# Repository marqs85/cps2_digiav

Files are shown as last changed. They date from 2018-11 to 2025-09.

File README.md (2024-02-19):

CPS2 digital AV interface (Rev 2)
==============

Overview
--------------------------
cps2_digiav is an add-on for Capcom CP System II and some other arcade boards. It enables digital video and audio output via HDMI connector. The project consists of a common interface PCB (`pcb/`) and board-specific FPGA firmware (`board/<board>/output_files/cps2_digiav.jic`).

Supported boards
--------------------------
* CPS1 (89626A)
* CPS2
* CPS3
* Neo Geo (MV1C, AES3-3 and AES3-6, possibly others as well)
* Toaplan V2

Hardware
--------------------------
The add-on [PCB](https://oshpark.com/shared_projects/fxG9hou9) design can be self-built or bought [pre-assembled](https://videogameperfection.com/products/cps2-cps3-digital-av-interface-diy-kit/).

* Installation typically requires a small number of additional components which are listed in board-specific READMEs.

More info and discussion
--------------------------
* [Forum topic](http://shmups.system11.org/viewtopic.php?f=6&t=59479&p=1266977)

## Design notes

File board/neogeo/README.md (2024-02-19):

CPS2 digital AV interface (Neo Geo version)
==============

Features (current)
--------------------------
* framelocked 59.19Hz output (59.60Hz on AES) with max. 40 scanline latency
  * 240p_CRT (for 15kHz CRTs and capture)
  * 480p_CRT (for 31kHz CRTs)
  * 720p (CEA)
  * 1280x1024 (VESA)
  * 1080p (CEA, vertical 4x)
  * 1080p (CEA, vertical 5x) [default]
  * 1600x1200 (VESA)
  * 1920x1200 (CVT-RB)
  * 1920x1440 (CVT-RB)
* 24bit/48kHz audio output

Installation
--------------------------
The add-on board can be installed on top of MVS PCB or AES home console. Installation instructions are provided for MV1C, NEO-AES3-3 and NEO-AES3-6 models, but the mod should be compatible with others too. The following additional parts are required:

* 2pcs 0805 10u SMD ceramic capacitors (MV1C only)
* ribbon cable
* [audio ADC board](../../pcb_neogeo_aadc) for models without NEO-YSA2 chip (present in MV1C and some others)
* hookup for PCB buttons
  * if using JAMMA buttons: 2x 10cm wires
  * if using separate buttons: 2pcs 0603 10k SMD resistors and TL2243 switch (or 2 external buttons connecting "vol+" and "vol-" pads to GND when pressed)

Installation instructions are found in doc/install.md (MV1C) and doc/install_aes.md (AES).

Usage
--------------------------
Board is controlled via TL2243 (or via 2 external buttons depending on installation).

Bindings outside OSD:
* VOL- (hold 1.5s): enable OSD

Bindings inside OSD:
* VOL-: next option
* VOL+: next value / select function

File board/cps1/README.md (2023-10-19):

CPS2 digital AV interface (CPS1 version)
==============

Features (current)
--------------------------
* framelocked 59.64Hz output with max. 40 scanline latency
  * 240p_CRT (for 15kHz CRTs and capture)
  * 480p_CRT (for 31kHz CRTs)
  * 720p (CEA)
  * 1280x1024 (VESA)
  * 1080p (CEA, vertical 4x)
  * 1080p (CEA, vertical 5x) [default]
  * 1600x1200 (VESA)
  * 1920x1200 (CVT-RB)
  * 1920x1440 (CVT-RB)
* 24bit/48kHz audio output

Installation
--------------------------
The add-on board can be installed on top of CPS1 A-board (89626A revisions currently supported). The following additional parts are required:

* cps1_adapter PCB and related parts, see pcb_cps1_adapter folder
* 3pcs 2x5 U-type pin headers
* ribbon cable
* coaxial cable (~40cm)
* hookup for PCB buttons
  * if using JAMMA buttons: 2x 15cm wires
  * if using external buttons: wires and 2pcs 0603 10k SMD resistors
  * if using CPS2 I/O Interface, 1pcs of XHP-2, 1pcs ASXHSXH22K305 and 2pcs 0603 10k SMD resistors

Installation instructions are found in doc/install.md .

Usage
--------------------------
Board is controlled via two external buttons.

Bindings outside OSD:
* VOL- (hold 1.5s): enable OSD
* VOL+ (hold 1.5s): toggle scanline mode

Bindings inside OSD:
* VOL-: next option
* VOL+: next value / select function

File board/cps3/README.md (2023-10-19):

CPS2 digital AV interface (CPS3 version)
==============

Features (current)
--------------------------
* framelocked 59.60Hz output with max. 40 scanline latency
  * 240p_CRT (for 15kHz CRTs and capture)
  * 480p_CRT (for 31kHz CRTs)
  * 720p (CEA)
  * 1280x1024 (VESA) [std. aspect only]
  * 1080p (CEA, vertical 4x)
  * 1080p (CEA, vertical 5x) [default]
  * 1600x1200 (VESA) [std. aspect only]
  * 1920x1200 (CVT-RB)
  * 1920x1440 (CVT-RB) [std. aspect only]
* 24bit/48kHz audio output
* supports CPS3 standard and widescreen modes

Installation
--------------------------
The add-on board can be installed on top of CPS3 board, preferably close to JAMMA connector. The following additional parts are required:
* ribbon cable (~15cm, at least 5x4=20 conductors)
* coaxial cable (~50cm total)
* kynar wire (~50cm total)
* hookup for PCB buttons
  * if using JAMMA buttons: 2x 25cm wires
  * if using separate buttons: 2pcs 0603 10k SMD resistors and TL2243 switch (or 2 external buttons connecting "vol+" and "vol-" pads to GND when pressed)
  * if using CPS2 I/O Interface, 1pcs of XHP-2, 2pcs ASXHSXH22K305 and 2pcs 0603 10k SMD resistors

Signal hookup points are listed in doc/cps3_hookup_points.txt and instructions are in doc/install.md .

Usage
--------------------------
Board is controlled via TL2243 (or via 2 external buttons depending on installation).

Bindings outside OSD:
* VOL- (hold 1.5s): enable OSD
* VOL+ (hold 1.5s): toggle scanline mode

Bindings inside OSD:
* VOL-: next option
* VOL+: next value / select function

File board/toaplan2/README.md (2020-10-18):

CPS2 digital AV interface (Toaplan V2 version)
==============

Features (current)
--------------------------
* framelocked 59.4Hz output with max. 40 scanline latency
  * 240p_CRT (for 15kHz CRTs and capture)
  * 480p_CRT (for 31kHz CRTs)
  * 720p (CEA)
  * 1280x1024 (VESA)
  * 1080p (CEA, vertical 4x)
  * 1080p (CEA, vertical 5x) [default]
  * 1600x1200 (VESA)
  * 1920x1200 (CVT-RB)
  * 1920x1440 (CVT-RB)
* 24bit/48kHz audio output

Installation
--------------------------
The add-on board can be installed on top of Toaplan V2 boards. The following additional parts are required:

* cps1_adapter PCB and related parts, see pcb_cps1_adapter folder
* 2pcs 0603 10k SMD resistors and TL2243 switch (or 2 external buttons connecting "vol+" and "vol-" pads to GND when pressed)
* ribbon cable
* coaxial cable (~40cm)

Installation instructions are found in doc/install.md .

Usage
--------------------------
Board is controlled via TL2243 (or via 2 external buttons depending on installation).

Bindings outside OSD:
* VOL- (hold 1.5s): enable OSD
* VOL+ (hold 1.5s): toggle scanline mode

Bindings inside OSD:
* VOL-: next option
* VOL+: next value / select function

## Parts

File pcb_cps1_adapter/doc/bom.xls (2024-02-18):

Id | Designator | Package | Quantity | Designation | Supplier and ref
1 | U1 | TSSOP-16_4.4x5mm_P0.65mm | 1 | 74LVC112 | https://www.digikey.fi/product-detail/en/texas-instruments/SN74LVC112APWR/296-8450-1-ND/377408
2 | U2 | SSOP-20_5.3x7.2mm_P0.65mm | 1 | WM8782 | https://www.digikey.fi/product-detail/en/cirrus-logic-inc/WM8782SEDS-V/598-2466-ND/5036698
3 | U3, | Package_SO:SOIC-16_3.9x9.9mm_P1.27mm | 1 | 74LVC157 | https://www.digikey.fi/en/products/detail/texas-instruments/SN74LVC157ADR/562891
4 | J1,J2,J3 | BCS-105-L-D-PE-BE | 3 | Conn_02x05_Counter_Clockwise | https://www.digikey.fi/products/en?keywords=BCS-105-L-D-PE-BE%20
5 | C2,C4,C6,C7,C9,C11 | SM0603_Capa_libcms | 6 | 0.1u | https://www.digikey.fi/product-detail/en/samsung-electro-mechanics/CL10B104KB8NNNC/1276-1000-1-ND/3889086
6 | C1,C3,C5,C8,C10 | SM0603_Capa_libcms | 5 | 10u | https://www.digikey.fi/product-detail/en/avx-corporation/0603ZD106KAT2A/478-10766-1-ND/7536554
7 | R1, R5 | SM0603_Resistor_libcms | 2 | 1.8k | https://www.digikey.fi/product-detail/en/yageo/RC0603FR-071K8L/311-1.80KHRCT-ND/729821
8 | R2, R3, R6 | SM0603_Resistor_libcms | 3 | 3.3k | https://www.digikey.fi/product-detail/en/yageo/RT0603FRE073K3L/YAG3354CT-ND/5418059
9 | R4 | SM0603_Resistor_libcms | 1 | 1M | https://www.digikey.fi/product-detail/en/yageo/RC0603FR-071ML/311-1.00MHRCT-ND/729791
10 | J4,J5 |  | 1 |  | https://www.digikey.fi/product-detail/en/samtec-inc/TSW-120-07-G-S/SAM1029-20-ND/1101307

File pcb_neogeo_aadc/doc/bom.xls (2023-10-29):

Ref | Qnty | Value | Cmp name | Package | MPN | Supplier and ref
C1, C2, C5, C7, C8, C9, | 6 | 10u | C_Small | custom_components:SM0603_Capa_libcms | CL10A106KP8NNNC
C3, C4, C6, C10, | 4 | 0.1u | C_Small | custom_components:SM0603_Capa_libcms | CC0603KRX7R9BB104
C11, C12, | 2 | 1u | C_Small | custom_components:SM0603_Capa_libcms | CL10A105KB8NNNC
R1, | 1 | 10k | R_Small | custom_components:SM0603_Resistor_libcms | 0603WAF1002T5E
R2, R3, | 2 | 15k | R_Small | custom_components:SM0603_Resistor_libcms | 0603WAF1502T5E
R4, R5, | 2 | 5k | R_Small | custom_components:SM0603_Resistor_libcms | 0603WAF4701T5E
R6, | 1 | 3.3k | R_Small | custom_components:SM0603_Resistor_libcms | 0603WAF3301T5E
U1, | 1 | 74LVC1G17 | 74LVC1G17 | Package_TO_SOT_SMD:SOT-23-5_HandSoldering | SN74LVC1G17DBVR
U2, | 1 | WM8782 | WM8782 | custom_components:TSSOP-20_4.4x6.5mm_Pitch0.65mm_Handsoldering | WM8782SEDS/RV
U3, | 1 | TLV70033_SOT23-5 | TLV70033_SOT23-5 | Package_TO_SOT_SMD:SOT-23-5_HandSoldering | TLV70033DDCR

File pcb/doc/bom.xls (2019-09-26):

Id | Designator | Package | Quantity | Designation | Supplier and ref | Notes
1 | P1 | VASCH5x2 | 1 | JTAG_CONN | https://www.digikey.fi/products/en?keywords=30310-6002HB | Developers should consider right angle unshrouded pin header which fits in the case with cable connected
2 | U15 | SOT-23-5_Handsoldering | 1 | TLV70018 | https://www.digikey.fi/product-detail/en/texas-instruments/TLV70018DDCT/296-25270-1-ND/2176448
3 | U12,U14 | SOT-23-5_Handsoldering | 2 | TLV70012 | https://www.digikey.fi/product-detail/en/texas-instruments/TLV70012DDCT/296-27218-1-ND/2260735
4 | U13 | SOT-23-5_Handsoldering | 1 | TLV70025 | https://www.digikey.fi/product-detail/en/texas-instruments/TLV70025DDCT/296-25568-1-ND/2197047
5 | J4 | HDMI_CONN-10029449-111RLF | 1 | HDMI_CONN | https://www.digikey.fi/product-detail/en/amphenol-fci/10029449-111RLF/609-4614-1-ND/2785376
6 | R46,R45,R1,R2,R5 | SM0603_Resistor_libcms | 5 | 2.2k | https://www.digikey.fi/product-detail/en/yageo/RC0603FR-072K2L/311-2.20KHRCT-ND/729963
7 | F2 | SM0603_Resistor_libcms | 1 | MF-FSMF020X-2 | https://www.digikey.fi/product-detail/en/bourns-inc/MF-FSMF020X-2/MF-FSMF020X-2CT-ND/2039387
8 | R41,R22,R21,R18,R17,R16,R6 | SM0603_Resistor_libcms | 7 | 10k | https://www.digikey.fi/product-detail/en/susumu/RR0816P-103-D/RR08P10.0KDCT-ND/432748
9 | FB4,FB2,FB1,FB3 | SM0603_Resistor_libcms | 4 | MPZ1608S221A | https://www.digikey.fi/product-detail/en/445-1565-1-ND/445-1565-1-ND/571895
10 | R24,R19,R4 | SM0603_Resistor_libcms | 3 | 4.7k | https://www.digikey.fi/product-detail/en/yageo/RC0603FR-074K7L/311-4.70KHRCT-ND/730159
11 | R23 | SM0603_Resistor_libcms | 1 | 25 | https://www.digikey.fi/product-detail/en/vishay-dale/CRCW060324R9FKEA/541-24.9HCT-ND/1179624
12 | R20 | SM0603_Resistor_libcms | 1 | 1k | https://www.digikey.fi/product-detail/en/yageo/RC0603FR-071KL/311-1.00KHRCT-ND/729790
13 | C108,C49,C1,C3,C10,C11,C12,C13,C26 | SM0603_Capa_libcms | 9 | 10u | https://www.digikey.fi/product-detail/en/murata-electronics-north-america/GRM188R60J106ME47D/490-3896-1-ND/965938
14 | C101,C99,C86,C85,C84,C83,C82,C81,C80,C79,C78,C77,C75,C74,C73,C69,C68,C67,C66,C65,C64,C63,C62,C61,C60,C59,C58,C57,C55,C54,C53,C51,C50,C48,C47,C46,C45,C44,C43,C42,C41,C40,C39,C6,C7,C8,C9,C14,C15,C16,C17,C18,C19,C20,C21,C22,C23,C25,C2 | SM0603_Capa_libcms | 59 | 0.1u | https://www.digikey.fi/product-detail/en/kemet/C0603C104K9RAC7867/399-15351-1-ND/7386749
15 | C98,C97,C96,C94,C92,C91,C89,C87 | SM0603_Capa_libcms | 8 | 1u | https://www.digikey.fi/product-detail/en/samsung-electro-mechanics/CL10A105MQ8NNNC/1276-1867-1-ND/3889953
16 | U10 | SOIC-8_3.9x4.9mm_Pitch1.27mm_Handsoldering | 1 | IS25LP016D-JBLE | https://www.digikey.fi/product-detail/en/issi-integrated-silicon-solution-inc/IS25LP016D-JBLE-TR/706-1599-1-ND/7672068
17 | C5 | SM0603_Capa_libcms | 1 | 47u | https://www.digikey.fi/product-detail/en/murata-electronics-north-america/GRM188R60J476ME15D/490-13247-1-ND/5877455
18 | D1 | SOD-323_Handsoldering | 1 | SD05-7 | https://www.digikey.fi/product-detail/en/diodes-incorporated/SD05-7/SD05DICT-ND/2052820
19 | R3 | SM0603_Resistor_libcms | 1 | 887 | https://www.digikey.fi/product-detail/en/panasonic-electronic-components/ERJ-PB3D8870V/P20277CT-ND/6214532
20 | U3,U4,U5 | TSSOP-20_4.4x6.5mm_Pitch0.65mm_Handsoldering | 3 | 74LVC245 | https://www.digikey.fi/product-detail/en/texas-instruments/SN74LVC245APWR/296-1233-1-ND/276501
21 | U16,U9,U8 | SOT-23-6_Handsoldering | 3 | SN74LVC2G17 | https://www.digikey.fi/product-detail/en/texas-instruments/SN74LVC2G17DBVR/296-13012-1-ND/479734
22 | D2,D3 | SLP2510P8 | 2 | RClamp0524P | https://www.digikey.fi/product-detail/en/semtech-corporation/RCLAMP0524PATCT/RCLAMP0524PACT-ND/2603616
23 | U1 | LQFP-64-1EP_10x10mm_Pitch0.5mm_Handsoldering | 1 | ADV7513 | https://www.digikey.fi/product-detail/en/analog-devices-inc/ADV7513BSWZ/ADV7513BSWZ-ND/3043405 | Alternative supplier: link (https://www.arrow.com/en/products/adv7513bswz/analog-devices)
24 | U2 | TQFP-144_thermal | 1 | 10CL025YE144C8N | https://www.digikey.fi/product-detail/en/intel-fpgas-altera/10CL025YE144C8G/10CL025YE144C8G-ND/7593572 | Alternative supplier: link (https://www.mouser.fi/ProductDetail/Intel-Altera/10CL025YE144C8G)
25 | U7 | SOT-223_Handsoldering | 1 | AP7361 | https://www.digikey.fi/product-detail/en/diodes-incorporated/AP7361C-33E-13/AP7361C-33E-13DICT-ND/5638331
26 | U6 | QFN-20-1EP_4x4mm_Pitch0.5mm_Handsoldering | 1 | SI5351C-B | https://www.digikey.fi/product-detail/en/silicon-labs/SI5351C-B-GM/336-2402-ND/3679850
27 | D4 | SOD-323_Handsoldering | 1 | ZHCS400TA | https://www.digikey.fi/product-detail/en/diodes-incorporated/ZHCS400TA/ZHCS400CT-ND/307928
28 | U11 | SSOP-28_5.3x10.2mm_Pitch0.65mm | 1 | SRC4190 | https://www.digikey.fi/product-detail/en/texas-instruments/SRC4190IDBR/296-41657-1-ND/5224401 | NOT ASSEMBLED
29 | J1,J2 | BCS-105-L-D-PE-BE | 2 | Conn_02x05 | https://www.digikey.fi/products/en?keywords=BCS-105-L-D-PE-BE%20 | Not needed for CPS3 installations
30 | R8,R7 | SM0603_Resistor_libcms | 2 | 10k | https://www.digikey.fi/product-detail/en/susumu/RR0816P-103-D/RR08P10.0KDCT-ND/432748 | Only for CPS1 and CPS3 installations
31 | SW1 | TL2243 | 1 | TL2243 | https://www.digikey.fi/product-detail/en/e-switch/TL2243/EG4606-ND/1794126 | Optional for CPS3 installation

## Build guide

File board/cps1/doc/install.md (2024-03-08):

A-board (revision 89626A-4) signal reference
--------------------------
[List of hookup points](./cps1_hookup_points.txt)

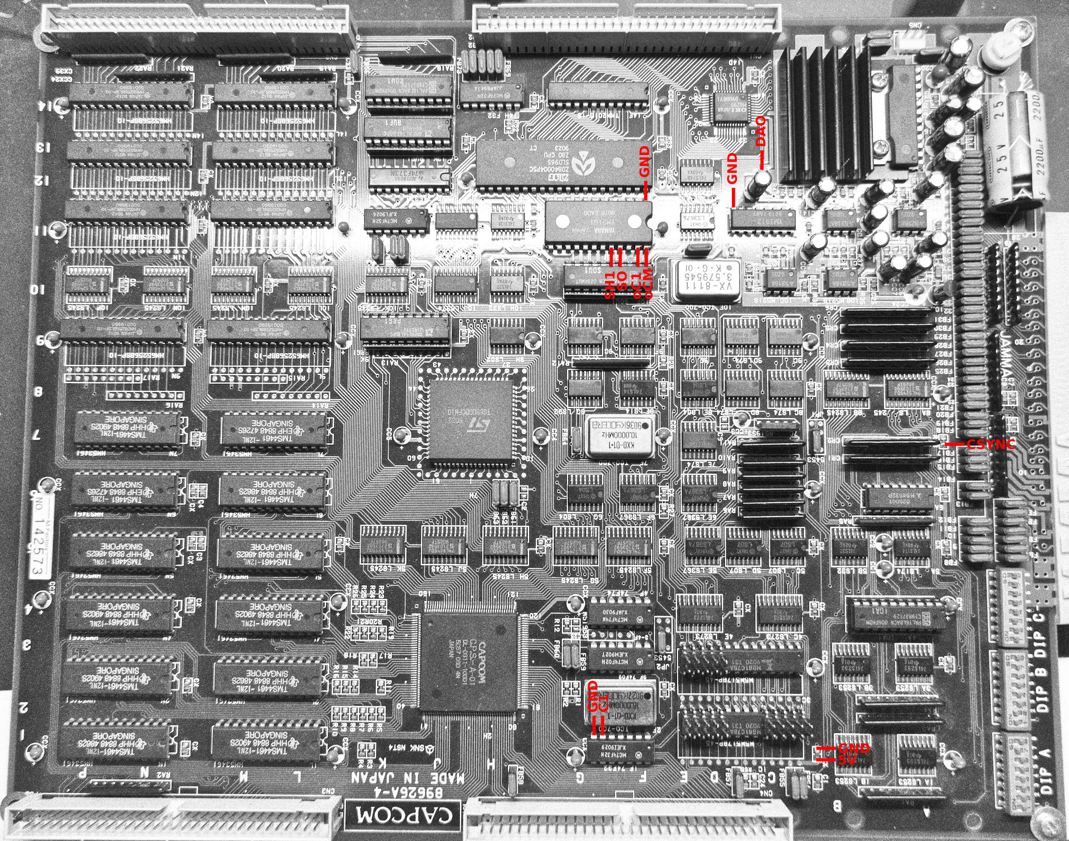
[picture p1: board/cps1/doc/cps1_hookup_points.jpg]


Step 1: Preparation
--------------------------

Solder 3pcs U-shaped 2x5 headers M5M RAM chips as shown in the image below. Solder BCS-105-L-D-PE-BE sockets on cps1_adapter (J1-3) and trim down pin metals underside the PCB. Make sure the adapter PCB fits in place before going forward. Solder R7+R8 (2x10k 0603 SMD resistors) on bottom of cps2_digiav board. Install cps2_digiav on top of adapter board via 4pcs 5-pin headers **without using spacers**.

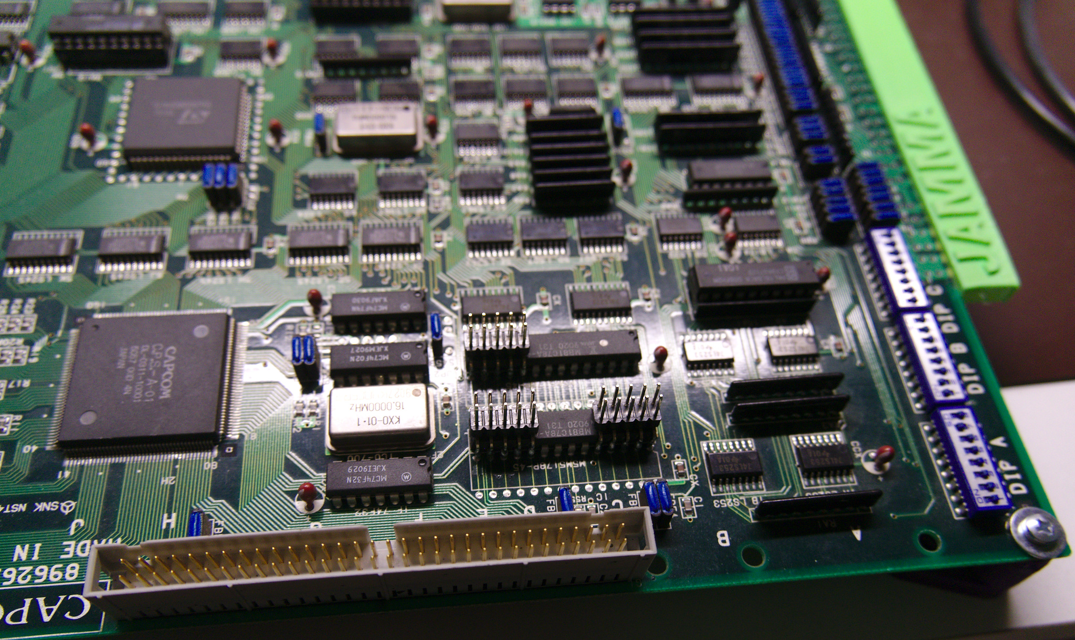
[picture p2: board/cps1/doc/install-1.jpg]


It is recommened to cover PAL 10A1 IC legs with electrical tape (at least on the side closer to PCB edge) as well as B-board bottom area above JTAG connector (full-length B-boards only). A-board resistor arrays (RA6-8) can be bent a little towards center so that adapter board PCB lies on level above them.

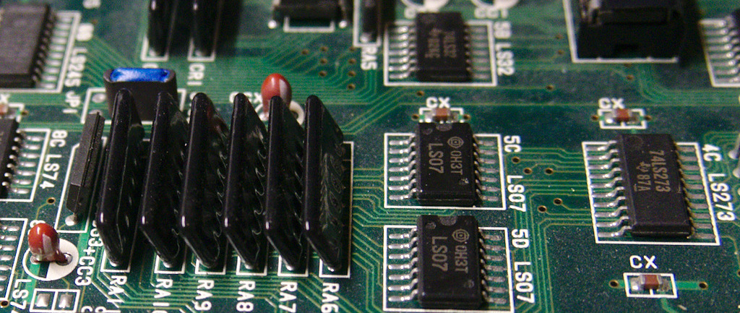
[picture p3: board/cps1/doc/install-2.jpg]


Step 2: Clock and sync signals
--------------------------

Clock is available on 74F32. It's mandatory to use a coax cable to avoid stability issues caused by noise. Composite sync is extracted from R28 as shown in the signal reference image (connect to HS pin on cps2_digiav).

Step 3: Audio, power and button signals
--------------------------

Audio is extracted from YM2151 and R49. Use coax cable for oCM and DAO signals.

The adapter board (since v1.3) has 4 QS_* pads reserved for CPS1 Multi installations (QSound support). On normal CPS1 installations these pads are left unconnected. With CPS1 Multi QS_SEL is connected to same endpoint as QSOUND wire and other QS_* pins to TDA1543 (it is recommended to use pin header like [this](https://www.digikey.fi/en/products/detail/sullins-connector-solutions/SWR25X-NRTC-S03-RB-BA/2769661)).

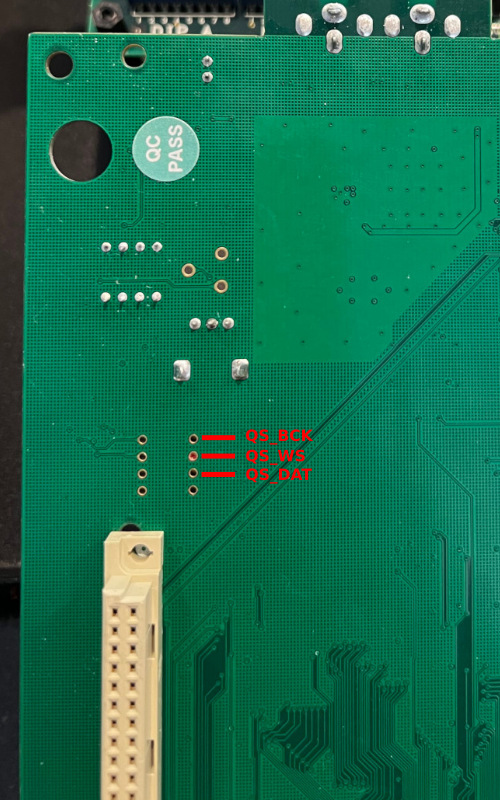
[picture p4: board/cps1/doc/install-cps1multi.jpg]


5V/GND can be extracted from certain CCX caps, e.g. the one shown in the signal reference image.

The board is operated via 2 keys which can be implemeted with one of the alternatives below:
* Wire vol-/vol+ pads to existing button lines on JAMMA connector (e.g. P1 credit & start).
* Wire two external pushbuttons to the board: one terminal to GND and another to vol-/vol+. Solder resistors R7 and R8 (10k 0603) to the board.
* If using CPS2 I/O Interface, vol-/vol+ pads can be wired to its up/down keys (see parts list on main README). R7 and R8 need to be installed as well.

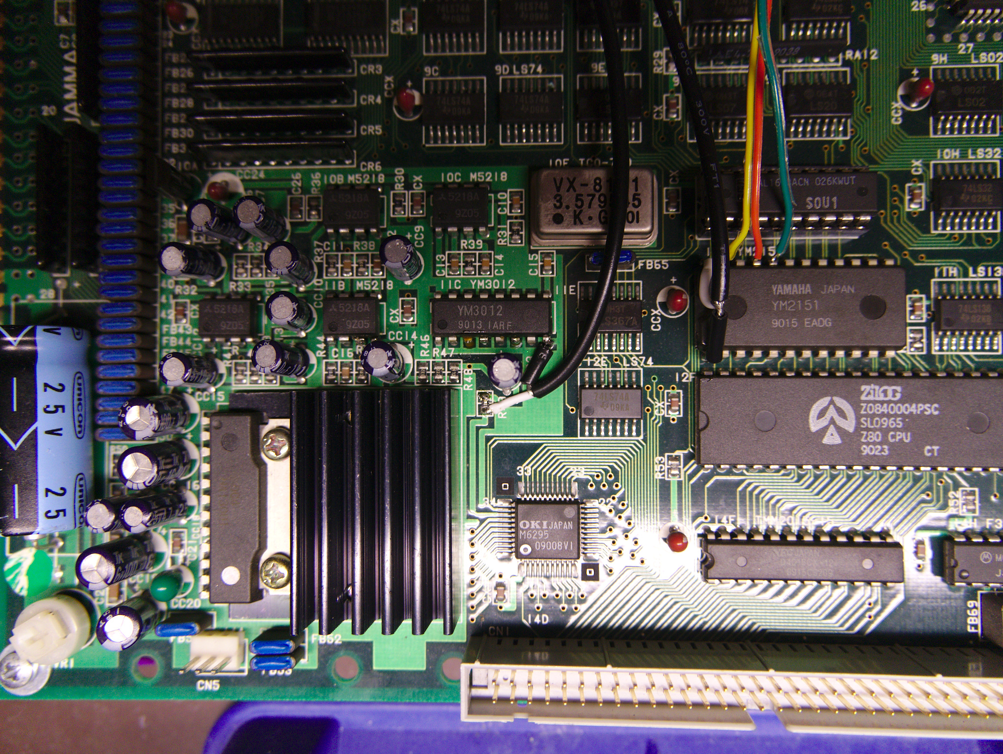
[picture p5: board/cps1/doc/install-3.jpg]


Step 4: Signals between cps1_adapter and cps2_digiav
--------------------------

Bridge SMD jumpers J3, J5 and J6 on cps2_digiav board. Connect I2S_*_o, SO and 3v3 from cps1_adapter to cps2_digiav as defined in the hookup point list. Add a jumper wire between C1 and C2 pads.

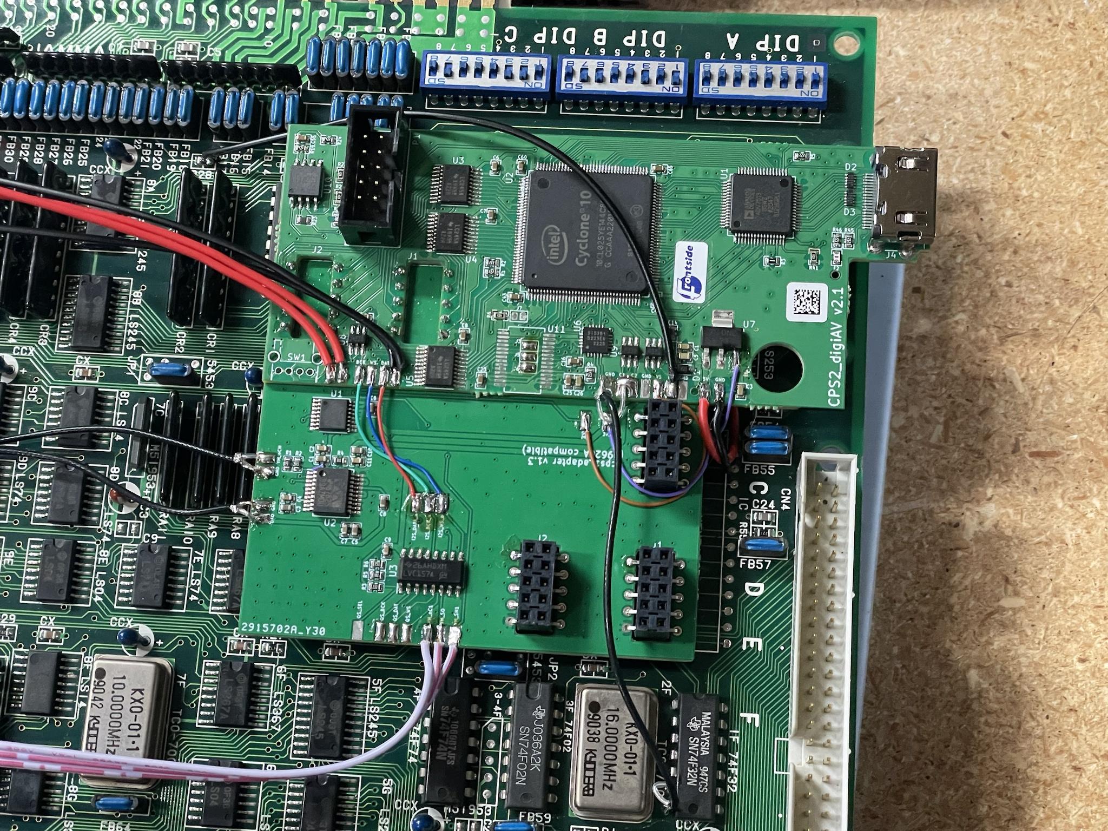
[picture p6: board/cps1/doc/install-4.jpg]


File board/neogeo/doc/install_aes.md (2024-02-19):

Neo Geo (NEO-AES3-3 / NEO-AES3-6) signal reference
--------------------------

[List of hookup points (AES3-3)](./aes3-3_hookup_points.txt)

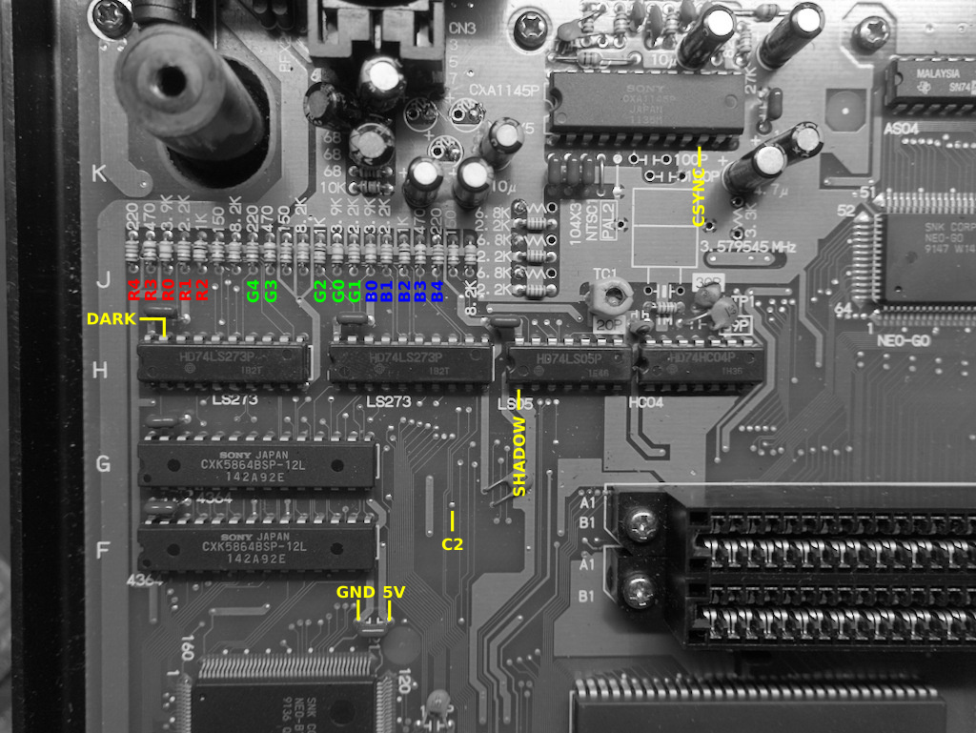
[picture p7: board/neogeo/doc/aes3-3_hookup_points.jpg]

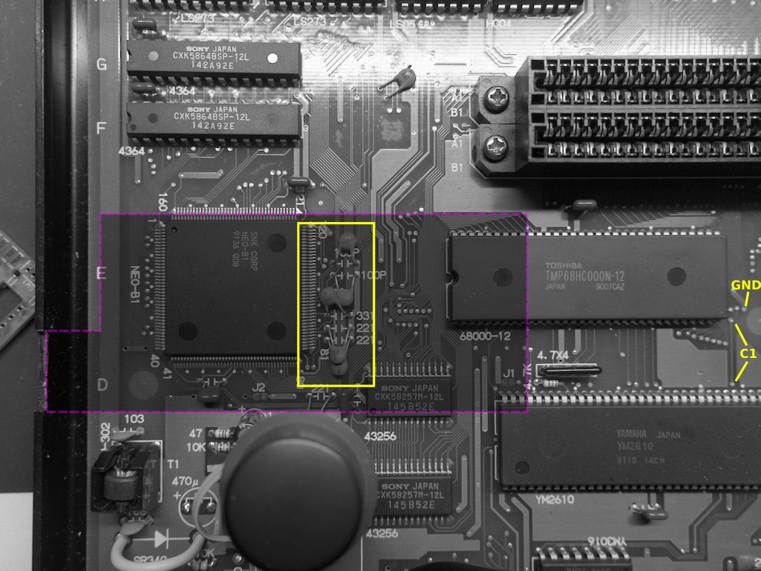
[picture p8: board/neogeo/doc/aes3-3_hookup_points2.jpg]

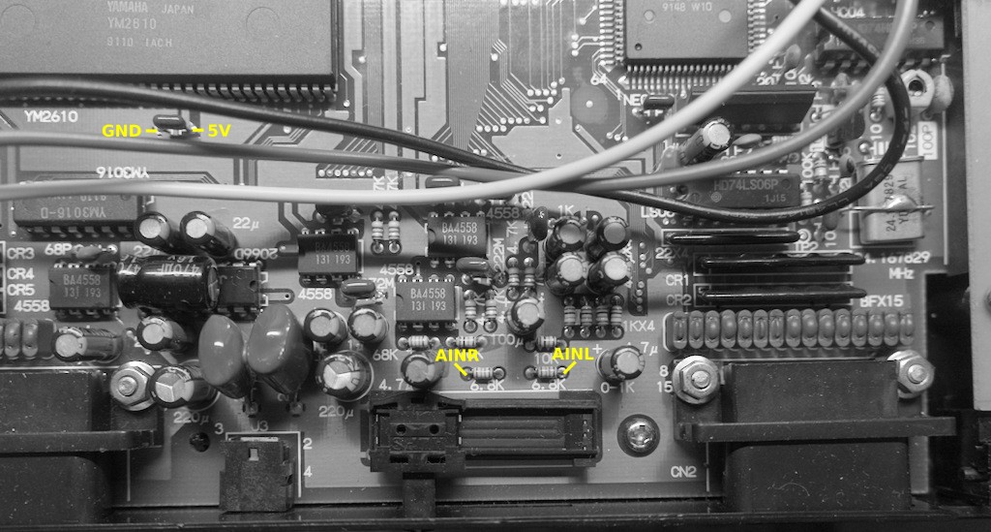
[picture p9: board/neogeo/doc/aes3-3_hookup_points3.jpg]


C1, C2, AINL, AINR are in slightly different place on AES3-6 as shown below:

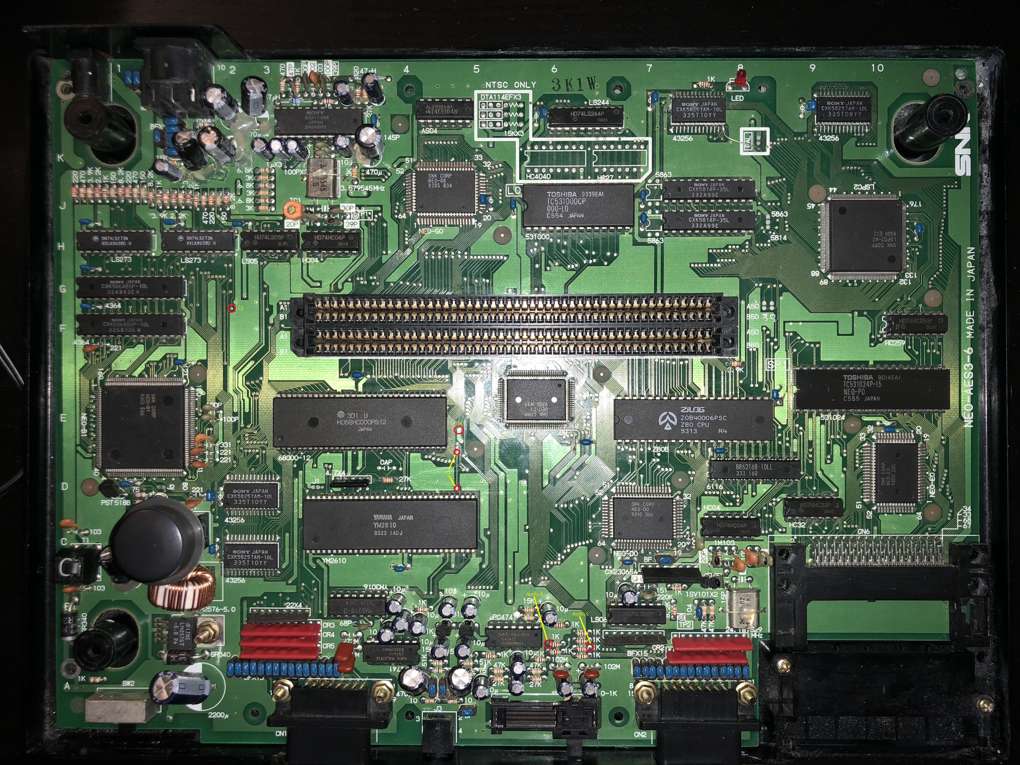
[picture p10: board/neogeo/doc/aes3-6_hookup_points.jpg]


Step 1: Preparation of cps2_digiav board
--------------------------

1. Bridge SMD jumpers J3, J5 and J6 on cps2_digiav board.

2. The board is operated via 2 keys which can be implemeted either by wiring vol-/vol+ pads to existing button lines on controller ports (e.g. P1 credit & D) or by using separate buttons. In the latter case, solder R7+R8 (2x10k 0603 SMD resistors) on bottom of cps2_digiav board and connect one end of the buttons to GND and other end to vol+/- pads.

3. Cut a 10cm piece of 16 conductor ribbon cable and split in into following pieces: 5 conductor (1pcs), 4 conductor (1pcs), 3 conductor (1pcs), 1 conductor (4pcs). Strip both ends of the wires and solder them to named holes around J1/J2 footprints on cps2_digiav as shown in the picture below (solitary wires for R0, G0, B0 and B4). Cut / trim the soldered ends since they will otherwise hinder installation. Tin other ends of the wires so that they can be easily soldered on the resistors on AES.

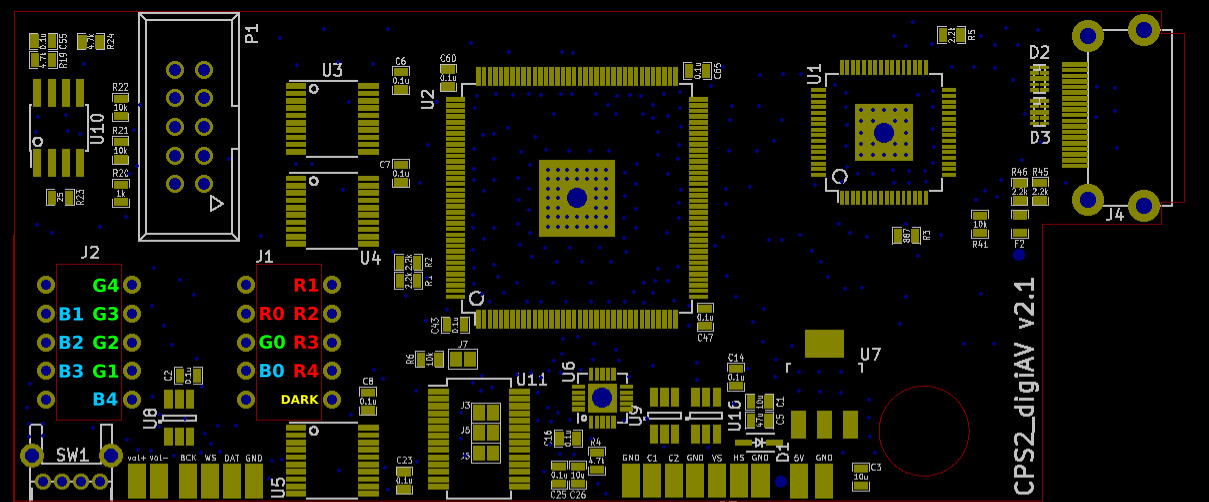
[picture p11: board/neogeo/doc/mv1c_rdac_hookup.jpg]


Step 2: Preparation of AES
--------------------------

1. If you plan on installing the board on the shaded area which is selected to minimize wire distances, bend down the capacitors in the yellow rectangle and make a small cutout for HDMI connector on lower part of the case.

2. Attach mounting tape pieces on top of NEO-B1 (double layer) and under cps2_digiav between the cutouts if the board is installed on the recommended location. Secure cps2_digiav board on its place.

Step 3: Power signals
--------------------------

Connect nearest 5V and GND points of AES to respective pads on cps2_digiav board with 2 short and sturdy wires.

Step 4: Clock and sync signals
--------------------------

Use coax cable for C1 and connect GND on both ends (cover unused vias next to upper C1 connection point on AES with electrical tape to avoid shorting them). C2 and CSYNC can be connected with kynar or similar thin wires.

Step 5: Audio signals
--------------------------

Install audio ADC board on top of YM2610 with mounting tape. Hook WS, DAT and BCK signals to cps2_digiav with a 3 conductor ribbon cable etc. Connect AILR and AINR pads to AES, and 5V and GND pads to nearest capacitor.

Step 6: Video signals
--------------------------

Connect 15 RGB wires from step 1 to the marked resistors (south side) on AES and hook 16th wire (DARK) to leftmost LS273 pin 19. As the last step, connect SHADOW (LS05 pin 1) to VS pad of cps2_digiav.

Step 7: Finalization
--------------------------

Power up and verify both audio and video works. Open cps2_digiav menu, select AES from XTAL freq option and save settings. Make a cutout on the upper part of AES case and put everything together.

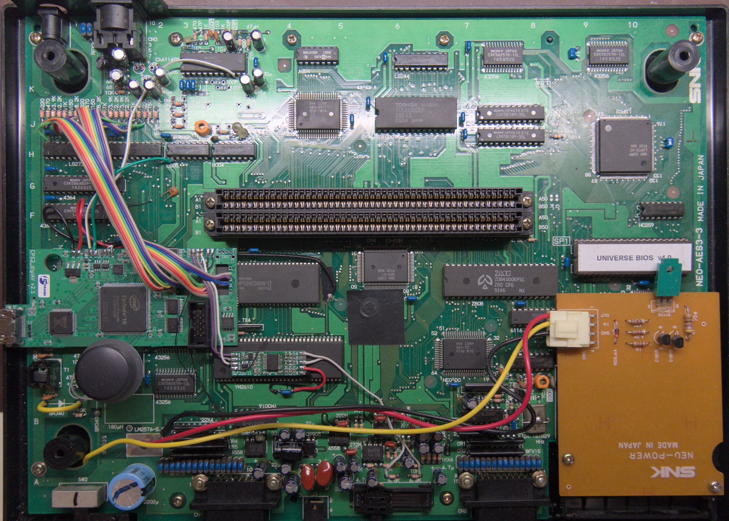
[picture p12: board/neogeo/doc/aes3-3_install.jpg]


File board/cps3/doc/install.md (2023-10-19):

Step 1: clock and sync signals
--------------------------
Clocks and syncs are available on bottom side of CPS3 board. Extract 42.9545MHz clock (C1) from right side of R74 and video clock (C2) from left side of R36. For C1 it's mandatory to use a coax cable to avoid stability issues caused by noise. For C2 I was able to use a short kynar wire without issues, but depending on installation a coax might be needed as well. Horizontal and vertical sync are combined on factory-installed add-on board housing a LS08 chip. Extract HS from IN1 and VS from IN2. Some boards have HS connected IN2 and VS to IN1 - try swapping them if you don't get proper sync/picture. On later CPS3 revisions the LS08 might also be integrated on the mainboard.

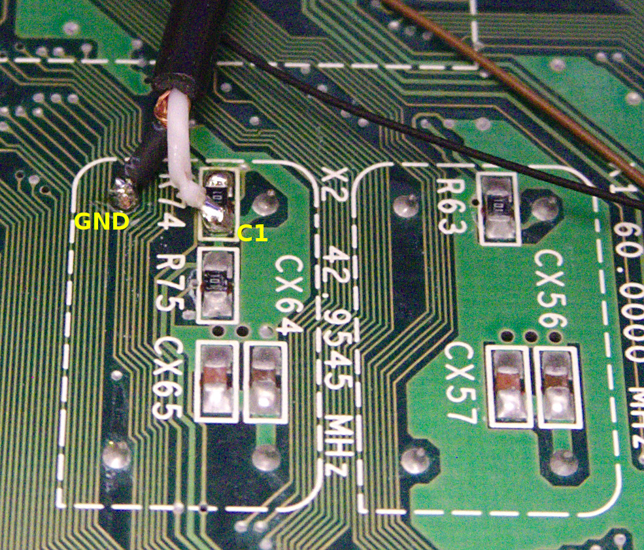
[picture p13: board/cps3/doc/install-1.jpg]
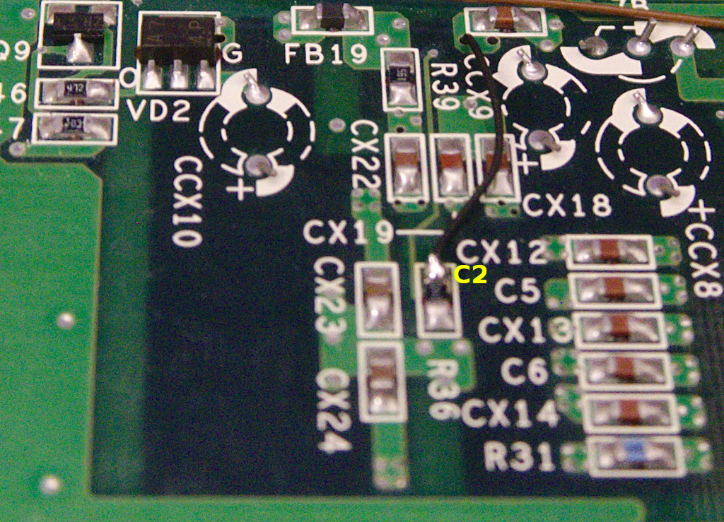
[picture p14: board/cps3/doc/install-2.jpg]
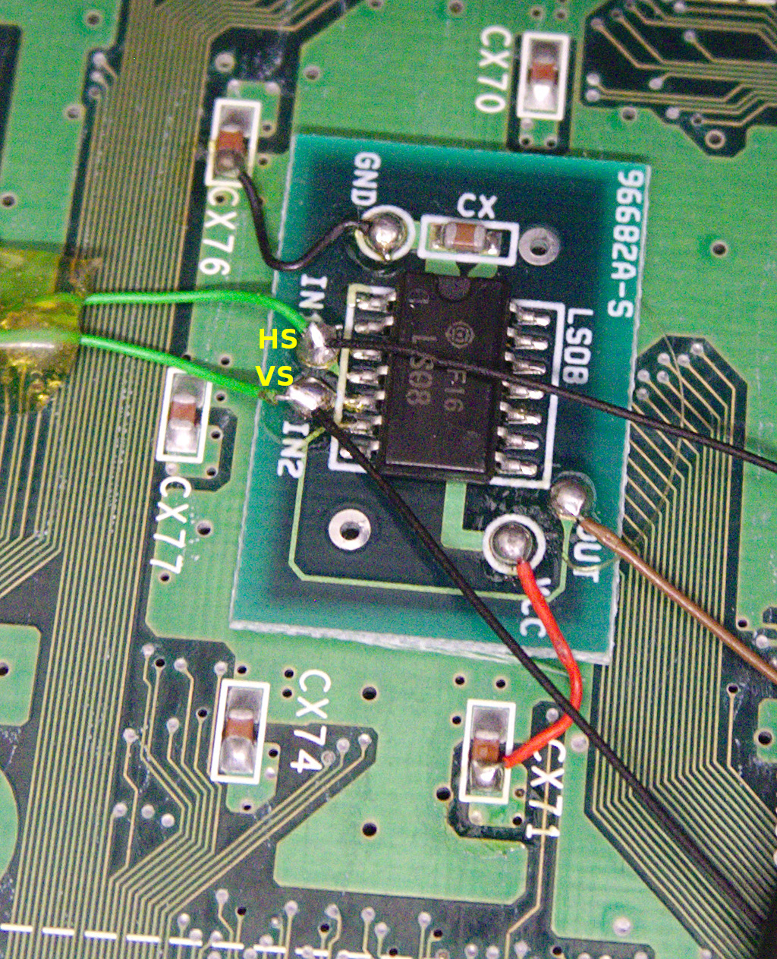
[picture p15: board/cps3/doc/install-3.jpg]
  

Step 2: RGB, audio and power signals
--------------------------

RGB, audio and power are easily available on top side of CPS3. Extract RGB and audio signals from RN7-RN3 resistor arrays as shown in the first image below. For BCK it's highly recommended to use a coax cable. 5V and GND can be extracted near JAMMA connector as shown in the second image.

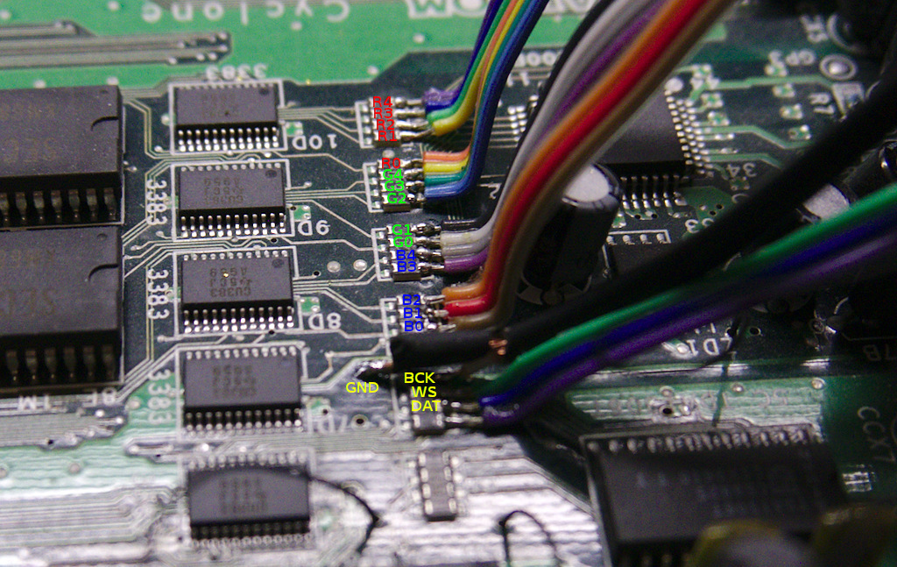
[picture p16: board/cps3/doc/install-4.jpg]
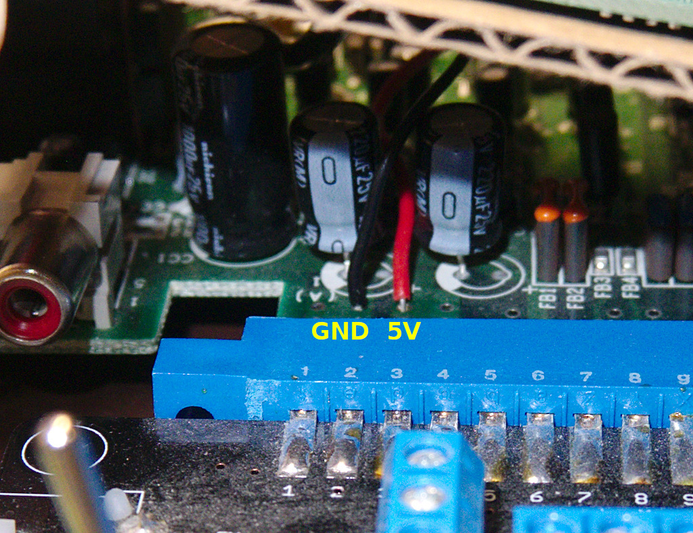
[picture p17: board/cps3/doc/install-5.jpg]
 

Step 3: Preparation of cps2_digiav board
--------------------------

Bridge SMD jumpers J3, J5 and J6 on top side of the PCB.

The board is operated via 2 keys which can be implemeted with one of the alternatives below:
* Wire vol-/vol+ pads to existing button lines on JAMMA connector (e.g. P1 credit & start).
* Install R7+R8 (2x10k 0603 SMD resistors) and SW1 (TL2243). SW1 can be substituted via 2pcs external buttons of which one end is connected to GND and other end to vol+/- pads.
* If using CPS2 I/O Interface, vol-/vol+ pads can be wired to its up/down keys (see parts list on main README). R7 and R8 need to be installed as well.

Step 4: RGB hookup to cps2_digiav board
--------------------------

RGB signals are hooked to socket footprint holes on cps2_digiav board as illustrated below. Add a jumper wire between the holes connected by a magenta line in the image to avoid a floating extra input pin.

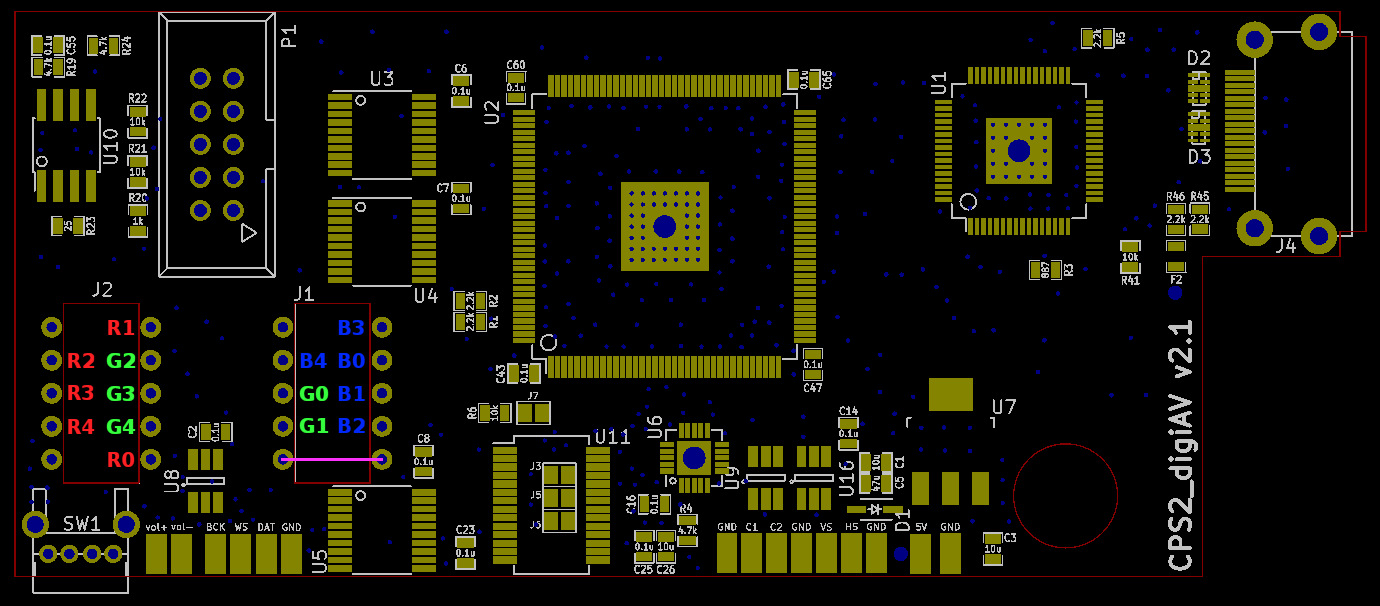
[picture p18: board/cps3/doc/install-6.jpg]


Step 5: Finalization
--------------------------

Hook the remaining signals to cps2_digiav board. Use mounting tape to attach the board to a suitable place on CPS3 mainboard.

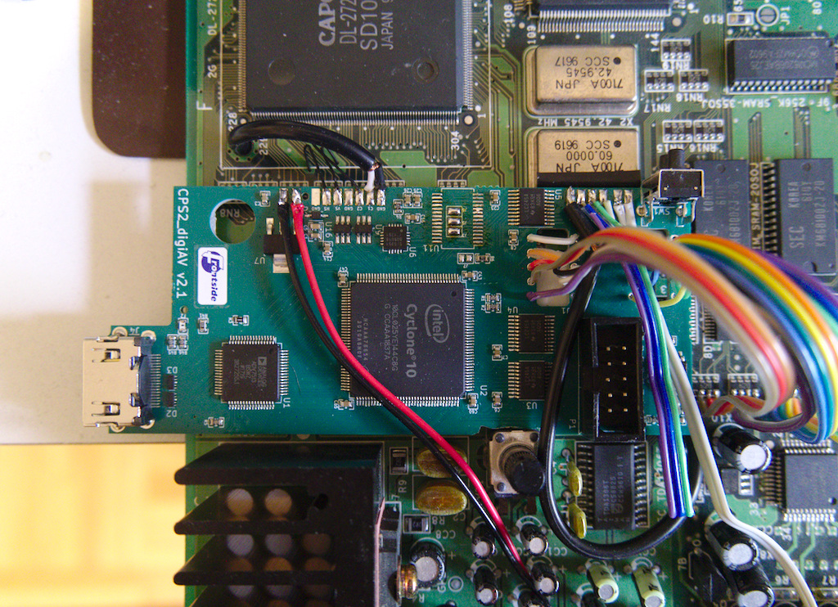
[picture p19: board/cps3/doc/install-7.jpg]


After installation, FPGA firmware (output_files/cps2_digiav.jic) needs to be flashed (if board wasn't pre-flashed) via JTAG using Altera USB Blaster -compatible programmer while CPS3 is powered on.

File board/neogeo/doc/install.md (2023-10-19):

Neo Geo (MV1C) signal reference
--------------------------

[List of hookup points](./mv1c_hookup_points.txt)

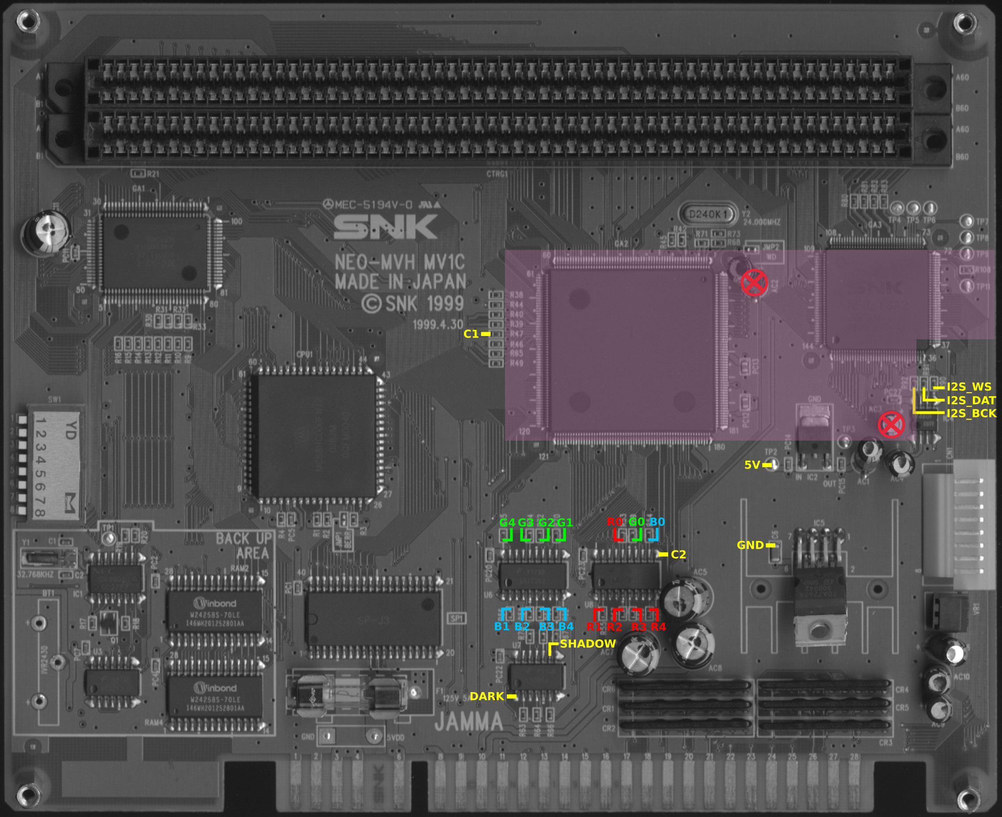
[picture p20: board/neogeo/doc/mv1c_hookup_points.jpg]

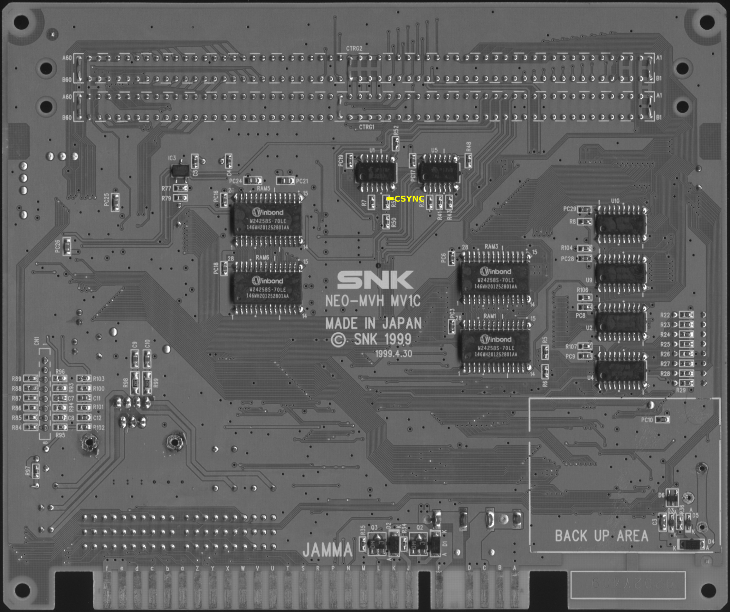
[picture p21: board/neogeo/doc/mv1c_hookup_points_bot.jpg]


Step 1: Preparation of MV1C
--------------------------

1. If you plan on installing the board on the shaded area which is selected to minimize wire distances, remove 2 marked electrolytic caps (AC2-3) and replace them with SMD ceramic caps (I used 0805 10uF ones).

2. Attach mounting tape pieces on top of GA2 and GA3 chips if the board is installed on the recommended place. Don't remove protective layer from top of the mounting tape yet since some hookup points are beneath the area where cps2_digiav PCB is to be placed.

Step 2: Preparation of cps2_digiav board
--------------------------

1. Bridge SMD jumpers J3, J5 and J6 on cps2_digiav board.

2. The board is operated via 2 keys which can be implemeted either by wiring vol-/vol+ pads to existing button lines on JAMMA connector (e.g. P1 credit & D) or by using separate buttons. In the latter case, solder R7+R8 (2x10k 0603 SMD resistors) on bottom of cps2_digiav board. If you want to add on-board button module, solder SW1 (TL2243). For external buttons (2pcs), connect their one end to GND and other end to vol+/- pads.

3. Cut a 10cm piece of 16 conductor ribbon cable and split in into following pieces: 5 conductor (1pcs), 4 conductor (1pcs), 3 conductor (2pcs), 1 conductor (1pcs). Strip both ends of the wires and solder them to named holes around J1/J2 footprints on cps2_digiav as shown in the picture below (solitary wire for DARK). Tin their other ends so that they can be easily soldered on SMD caps on MV1C.



Step 3: Power signals
--------------------------

Connect 5V and GND points of MV1C to respective pads on cps2_digiav board with 2 short and sturdy wires.

Step 4: Clock and sync signals
--------------------------

Use 3 kynar wires to connect C1, C2 and CSYNC (bottom side) points of MV1C to cps2_digiav. Bring CSYNC wire on top side through one of the vias near TP2 and connect it to HS pad.

Step 5: Audio signals
--------------------------

Hook WS, DAT and BCK signals to cps2_digiav with a 3 conductor ribbon cable.

Step 6: Board attachment
--------------------------

Now that all signals except video are connected, remove the protective layer from mounting tape pieces and secure cps2_digiav board on its place.

Step 7: Video signals
--------------------------

Connect 15 RGB wires from step 2 to the marked SMD resistors (LS273 side) on MV1C and hook 16th wire (DARK) to PC22 pin 1. As the last step, connect SHADOW (PC22 pin 9) to VS pad of cps2_digiav.

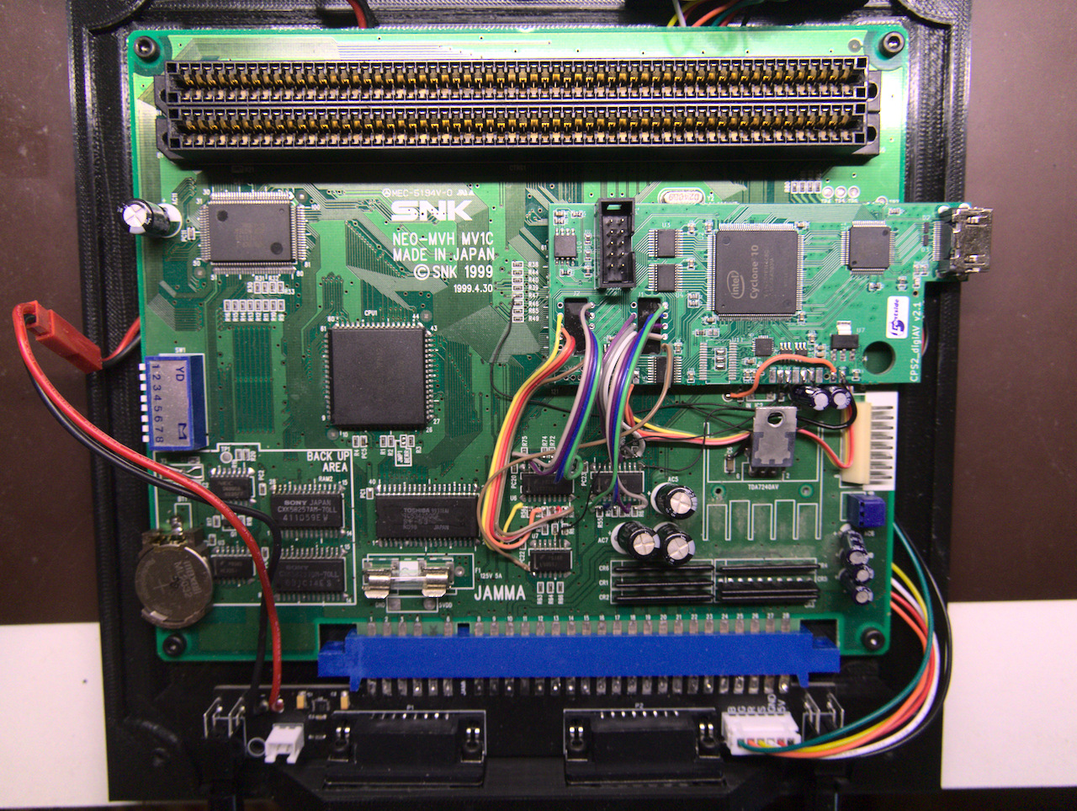
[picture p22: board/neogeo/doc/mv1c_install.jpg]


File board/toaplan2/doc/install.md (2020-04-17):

Toaplan V2 (Knuckle Bash) signal reference
--------------------------
This guide is for Knuckle Bash PCB. Installation to other Toaplan V2 boards should be similar.

[List of hookup points](./toaplan2_hookup_points.txt)

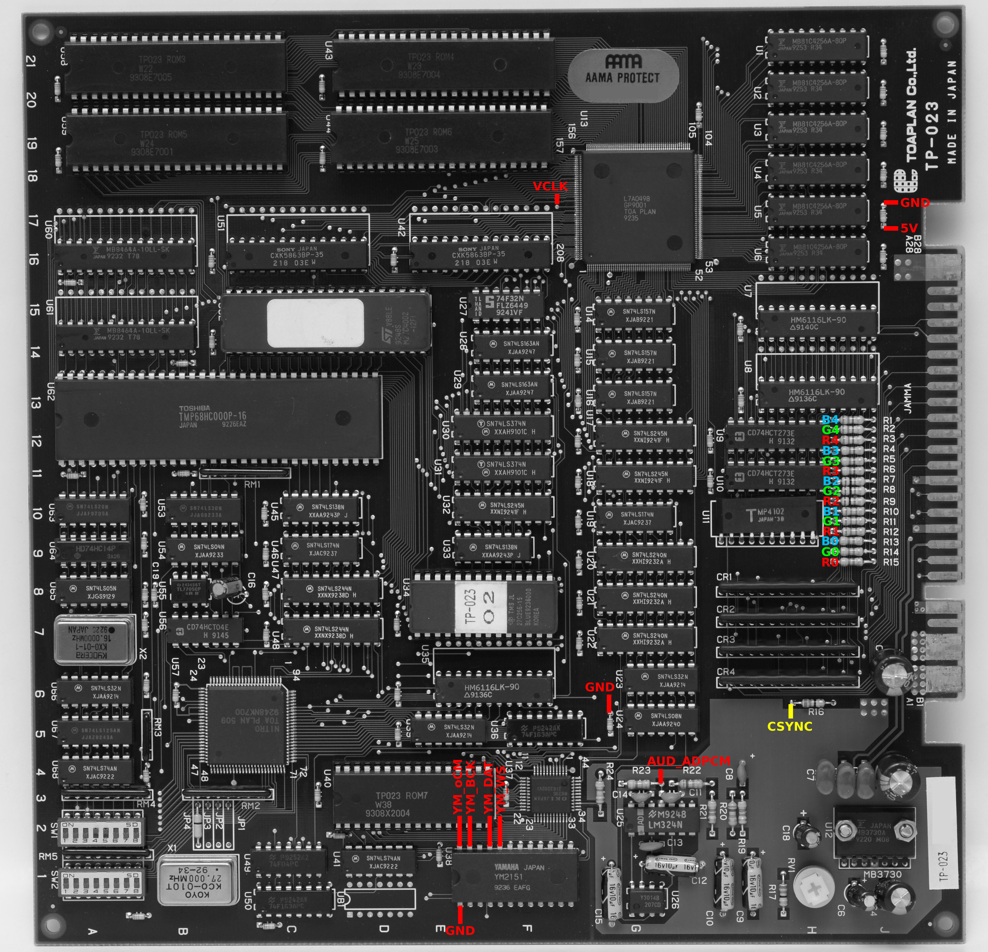
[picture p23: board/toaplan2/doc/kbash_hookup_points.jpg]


Step 1: Preparation of cps2_digiav board
--------------------------

Solder R7+R8 (2x10k 0603 SMD resistors) on bottom of cps2_digiav board. If you want to add on-board button module for operation control, solder SW1 (TL2243). For external buttons (2pcs), connect their one end to GND and other end to btn_vol+/- pad.

Step 2: Preparation of cps1_adapter+cps2_digiav combo
--------------------------

1. Install cps2_digiav on top of cps1_adapter board via 4pcs 5-pin headers as illustrated below

2. Bridge SMD jumpers J3, J5 and J6 on cps2_digiav board

3. Connect the following pads with 6 short wires as shown in the illustration (magenta lines):

* J3 (cps2_digiav) <-> oC1 (cps1_adapter)
* J5 (cps2_digiav) <-> SH1 (cps1_adapter)
* VS (cps2_digiav) <-> SO (cps1_adapter)
* U7 rightmost pin (cps2_digiav) <-> 3v3 (cps1_adapter)
* U7 leftmost pin (cps2_digiav) <-> 5V (cps1_adapter)
* J1 pins (cps1_adapter) on the bottom 

4. Cut 10cm piece of 15 conductor ribbon cable and split in into following pieces: 5 conductor (1pcs), 4 conductor (1pcs), 3 conductor (2pcs). Strip both ends of the wires and connect other ends to named holes around J1/J2 footprints on cps1_adapter (ref. image below). 

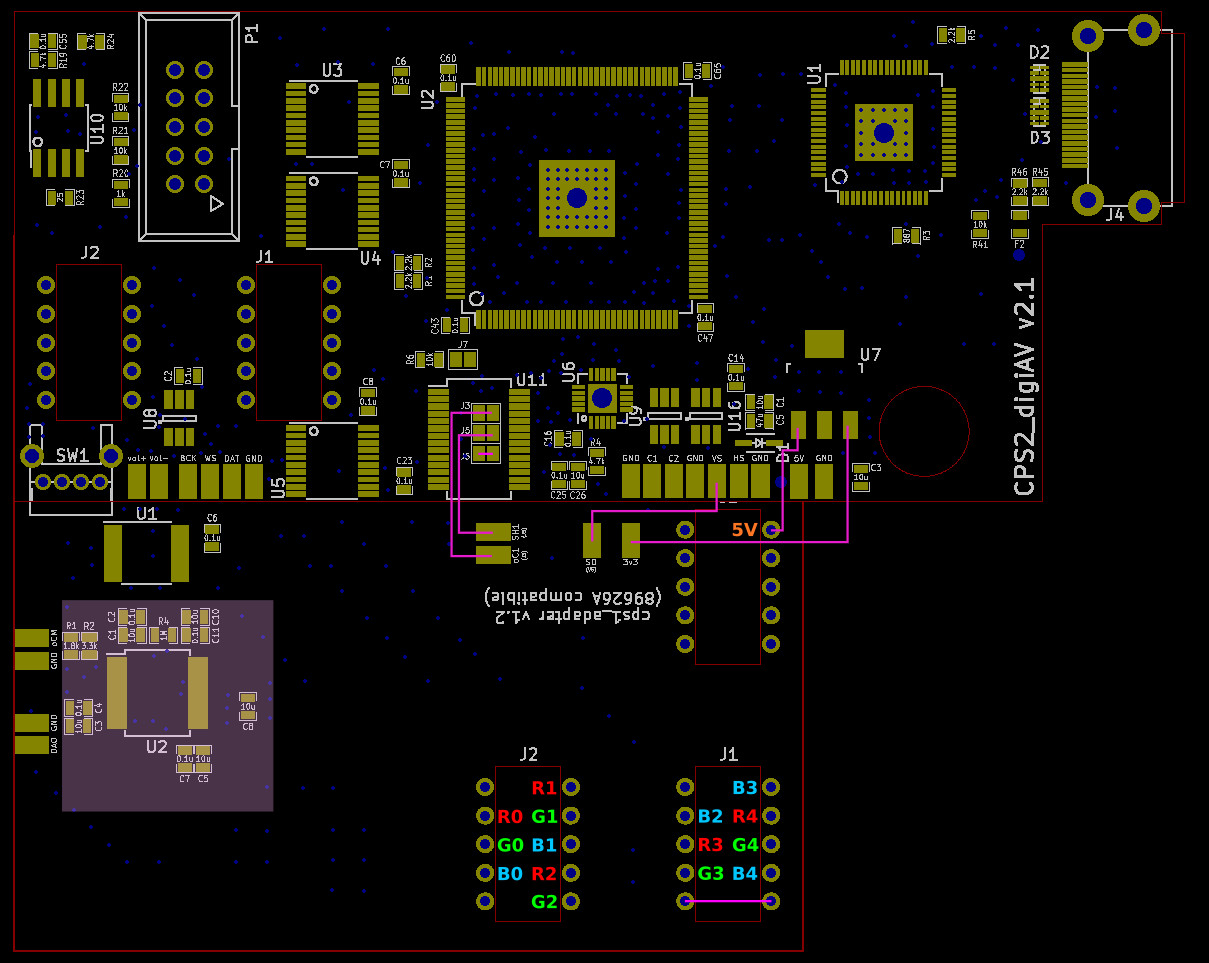
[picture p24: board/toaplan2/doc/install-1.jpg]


Step 3: Preparation of Toaplan V2 board
--------------------------

Place 3 mounting tape pieces on top of the Toaplan V2 chips as shown below. Before attaching the adapter combo, solder short wires on 5V/GND pair near Toaplan logo. Then position and place the mod board combination on Toaplan PCB and connect other ends of the 5V/GND wires on respective pads on cps2_digiav board. Lastly, connect VCLK from other side of adapter combo to C1 and C2 pads on cps2_digiav board. Preferably use as short as possible kynar wire and route it underside the mod board combination.

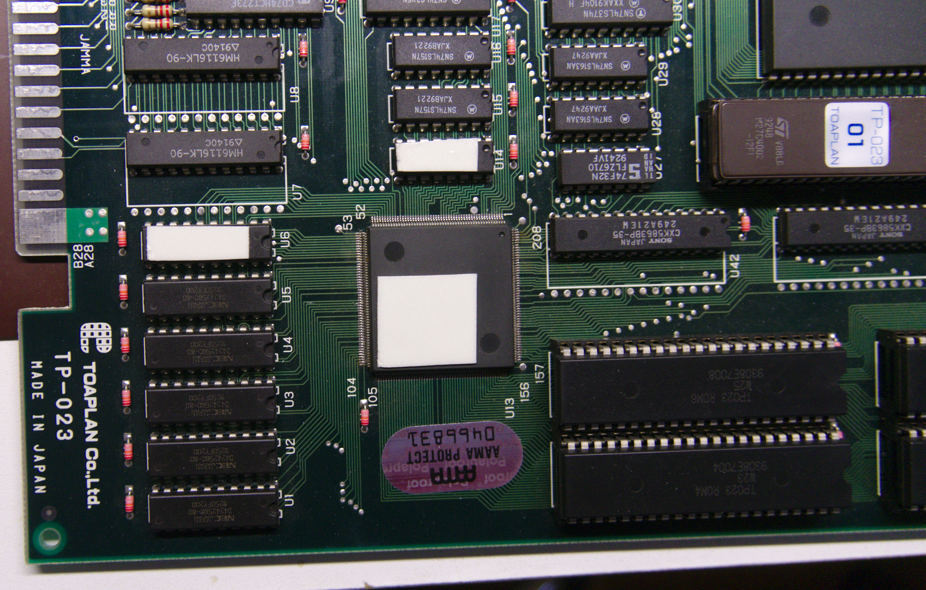
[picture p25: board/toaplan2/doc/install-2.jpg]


Step 4: Video and sync signals
--------------------------

Connect other ends of the ribbon cable groups (from step 2) to R2R DAC resistors near JAMMA connector. Connect CSYNC from R16 to HS pin on cps2_digiav board.

Step 5: Audio signals
--------------------------

OPM audio is extracted from YM2151 and ADPCM audio from R23. Use coax cables to connect YM_oCM and AUD_ADPCM signals to corresponding pads (oCM and DAO) on cps1_adapter. Connect grounds on both ends to the nearest places as designated. Lastly, use a pice of ribbon cable to connect YM_BCK, YM_DAT and YM_WS to corresponding pads (BCK, DAT and WS) on cps2_digiav. Avoid running the cable on top of noise-sensitive area around U2 on cps1_adapter (shaded in the earlier illustration).

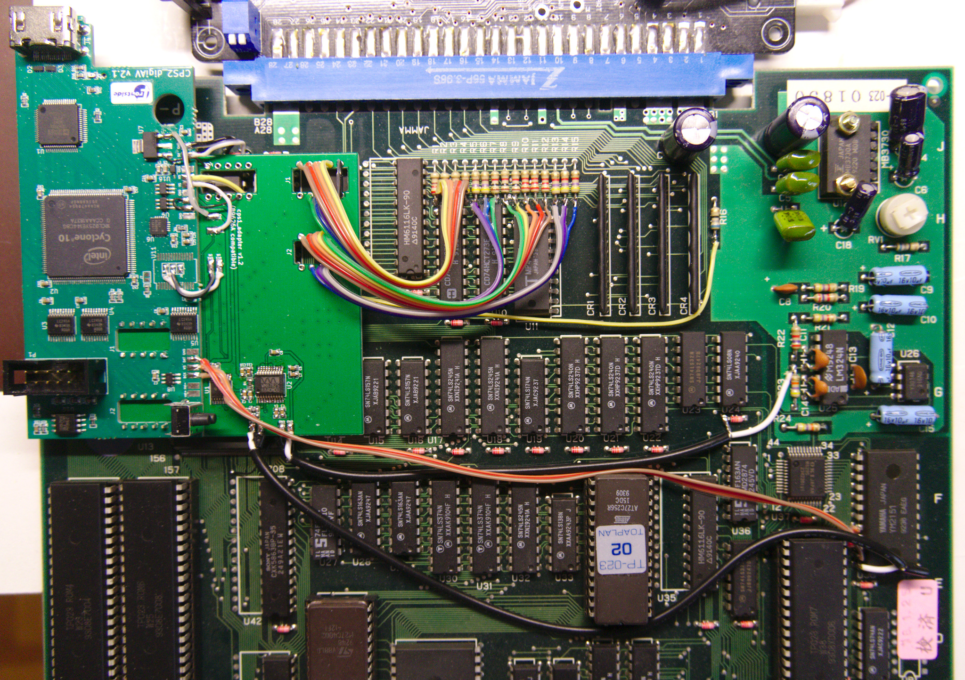
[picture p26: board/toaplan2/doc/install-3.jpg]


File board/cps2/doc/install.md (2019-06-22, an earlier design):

A-board signal reference
--------------------------
[List of hookup points](./cps2_hookup_points.txt)

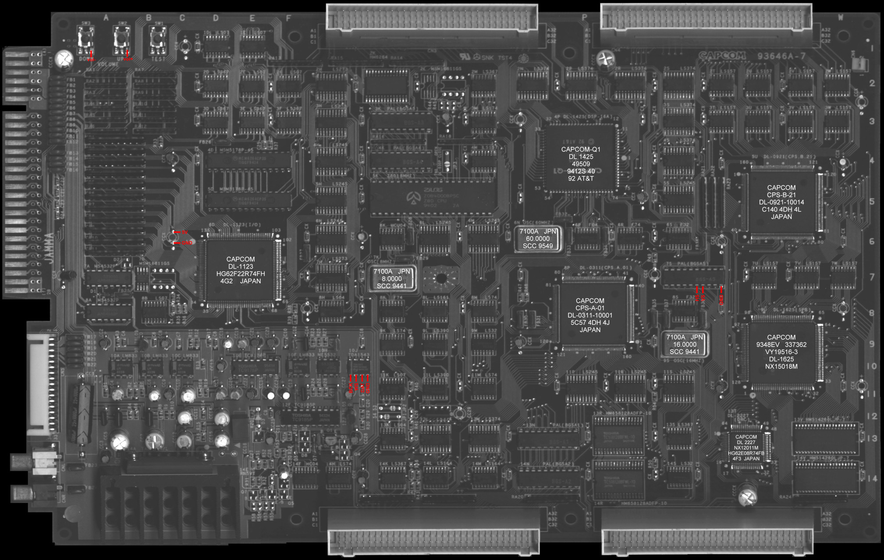
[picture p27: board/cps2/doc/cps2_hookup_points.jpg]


Step 1: clock and sync signals
--------------------------
Clock is available on bottom side of A-board. Extract 16MHz clock (C1) below the oscillator as shown in the image below. It's mandatory to use a coax cable to avoid stability issues caused by noise. Horizontal and vertical sync signals can be extracted from 7S - PAL (BGSA5) as shown in signal reference.

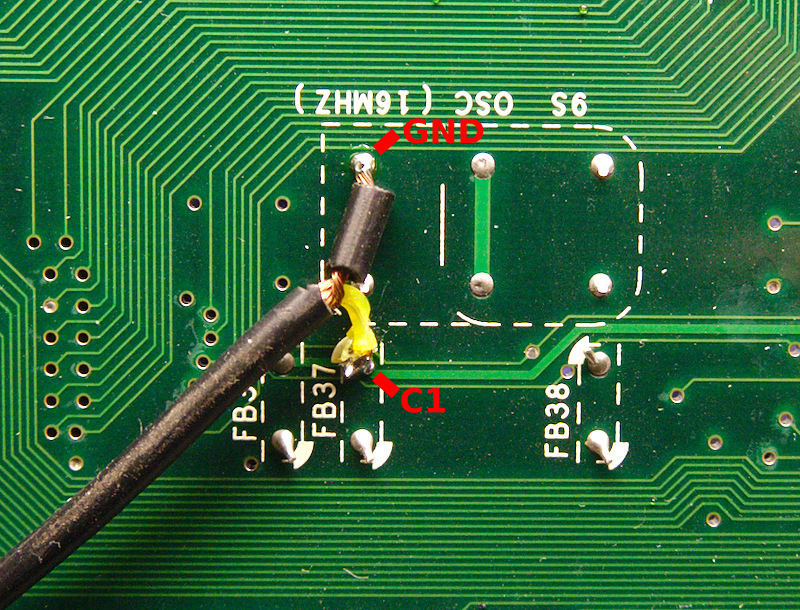
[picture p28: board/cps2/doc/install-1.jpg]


Step 2: RGB, audio, power and button signals
--------------------------

2pcs U-shaped 2x5 headers are used to tap RGB signals from M5M RAM chips as shown in the image below. Audio is extracted from 10J - TDA1543 as shown in signal reference and power can be easily taken e.g. from empty CCX cap footprints. Vol- and vol+ signals are taken from respective buttons as shown in signal reference.

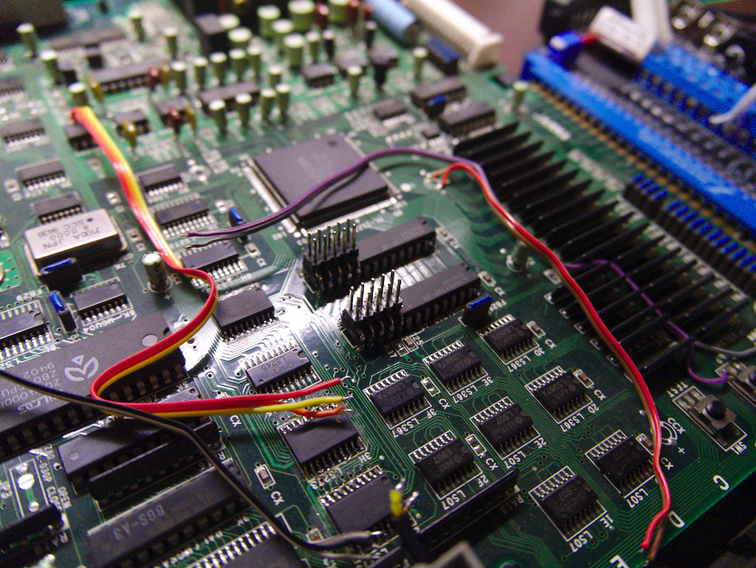
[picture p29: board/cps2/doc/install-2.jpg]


Step 3: Preparation of cps2_digiav board
--------------------------

Solder BCS-105-L-D-PE-BE sockets on their places and trim down pin metals underside the PCB. Bridge SMD jumpers J3, J5 and J6 on top side of cps2_digiav PCB.

Step 4: Board installation
--------------------------

Place the add-on board on top of the CPS2 board so that the sockets are aligned to headers. Connect all signal & power wires, and add a jumper wire between cps2_digiav C1 and C2 pads.

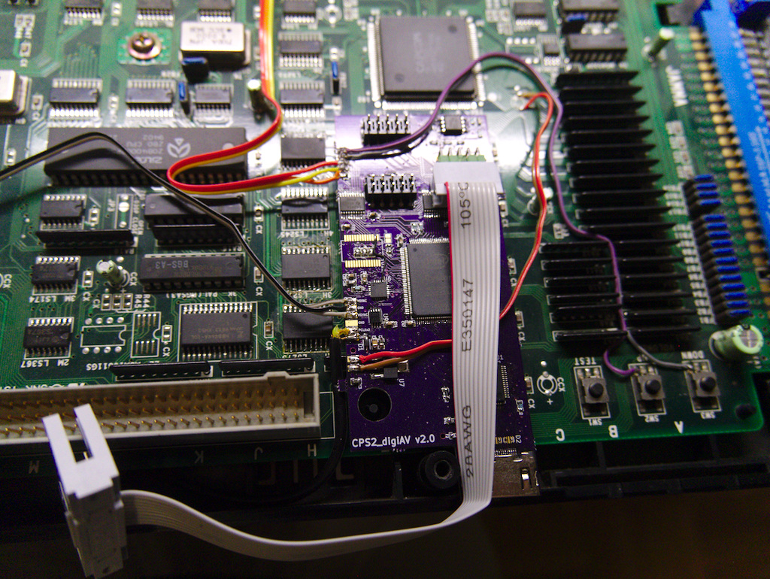
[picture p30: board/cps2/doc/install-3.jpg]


Step 5: Finalization
--------------------------

Make a small cutout for HDMI connector in the CPS2 case as illustrated below. If you want to enable later access to JTAG connector without the need of removing top part of A-board case (which also tends to lift up the add-on board), there are two options. It's possible to either replace the JTAG connector with an extension cable that goes outside of the case, or make another cutout on the A-board case on top of the connector.

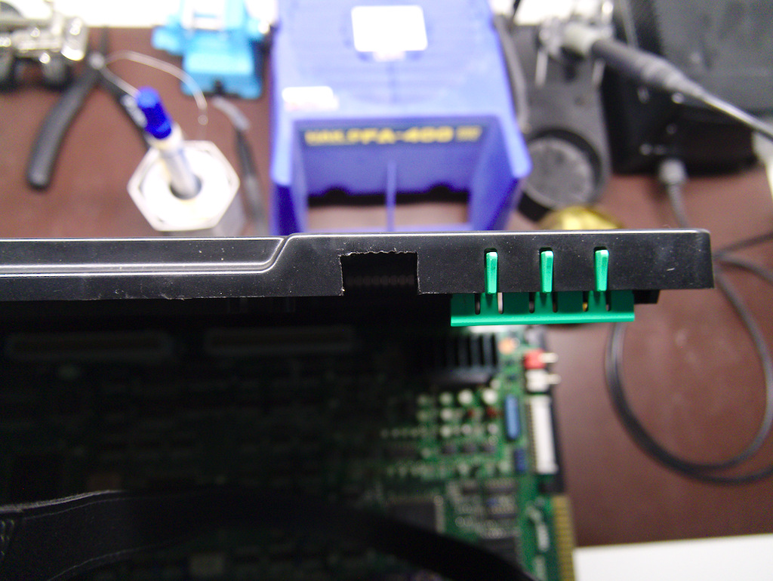
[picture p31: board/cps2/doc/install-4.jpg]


Before closing the case, FPGA firmware (output_files/cps2_digiav.jic) needs to be flashed (if board wasn't pre-flashed) via JTAG using Altera USB Blaster -compatible programmer while CPS2 is powered on.

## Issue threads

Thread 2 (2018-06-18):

Bom File

networkingyuppy, 2018-06-18:
Hi there,
Was wondering if you have a BOM file to grab the parts needed for the project.

marqs85, 2018-06-18:
Just added that under pcb/doc/

Closed 2018-06-18.

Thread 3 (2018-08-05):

No Sync on digiAV.

networkingyuppy, 2018-08-05:
Hi there,
The board has been assembled and I was able to flash the firmware successfully on the CPS2 DigiAV board, but I'm not getting a sync signal at the moment with the board. Connected the PCLKx2 to pin 4 and grounded it on pin 7. Voltage on the 5v line shows reading of 7.65v running under an arcade cabinet while power and ground is connected to the CCX cap.

marqs85, 2018-08-05:
Which pin 4 and 7 are you referring to. [Here](https://www.niksula.hut.fi/~mhiienka/tmp/cps2_pclk_x2.jpg) is a pic of PCLKx2 connected just below the oscillator. Did you check whether that CCX cap is connected to 5v rail before hooking to it? 7.65V sounds abnormal and dangerous high for the board.

networkingyuppy, 2018-08-06:
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
This is a revision 4 cps2 a board. I'm getting the proper readings on the board. So basically the PCLKx2 is wired underneath the oscillator

marqs85, 2018-08-06:
Ok. I just added a pre-built .jic file on the repo (under output_files/) - I suggest trying that just in case something has gone wrong if you built the bitstream yourself earlier. If that doesn't help, you can try defining DEBUG and recompiling SW part (assuming you're familiar with the flow), after which some debug messages can be seen on nios2-terminal.

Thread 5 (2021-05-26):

Neo Geo Picture is shifted

tianfeng33, 2021-05-26:
Just installed this in my mv1c and it appears that the picture is shift to the left and not centered on a 16:9 screen.

marqs85, 2021-05-26:
I wonder if there are some differences among MV1C boards. I'm using [these](https://github.com/marqs85/cps2_digiav/blob/182518d1ffa17488bcf3e8286f79dc0d8cd8cc7b/board/neogeo/rtl/neogeo_frontend.v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) parameters which produced a centered picture for me. How much off is that in your case and is it consistent among different output modes?

tianfeng33, 2021-05-26:
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
This was the output on my tv.

tianfeng33, 2021-05-26:
I can put an AV board in this tonight and take a look at what this console would need from the OSSC.

marqs85, 2021-05-26:
Could you take a screenshot of test grid etc. where it is easier to see how much off it is horizontally? Or did you mean full 320px Neogeo width is sampled correctly but that is not centered on 16:9 output as the picture indicates?

tianfeng33, 2021-05-26:
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
yeah,  it is sampled correctly but the picture is shifted over to the left.

marqs85, 2021-05-26:
Ok, I'll take a look into this.

tianfeng33, 2021-05-26:
anything you need me to test I am down.  It is obviously not the end of the world. no information is being lost.

marqs85, 2021-06-04:
I wasn't able to reproduce the shift on my monitor, the only minor issue is last column of pixels getting blanked. Do you have the shift with just the pictured monitor? Non-standard refresh rate of MVS might cause issues with certain displays but I wouldn't expect to see shift even in these cases.

kimbapslice, 2023-08-23:
I am experiencing the same issue with the right side of the grid being cut off in all resolutions via hdmi to a 4k lg hd tv. Running this on an OMVS playing Samurai Shodown 2 mvs.

kimbapslice, 2023-08-23:
I will check with other tv's and report back.

kimbapslice, 2023-08-24:
I tested with a 1080p native Samsung tv today and a 720p native Sylvania, and both in all resolution modes had the right side missing a few pixels just like the screens above. The centering issue was much less pronounce on these 2 tv's.

marqs85, 2023-08-28:
The centering issue seems to specific to LG - perhaps they don't play nice with 59.19Hz refresh rate? Missing of the last column apparently is a feature of MV-1C and other late models, and there is even a warning about that on 240p suite grid test. I just tested analog output and last column was missing as well.

kimbapslice, 2023-08-28:
That's great! Thank you!

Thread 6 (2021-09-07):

Hookup points needed for CPS1 88617A A board

bf32987, 2021-09-07:
While there is documentation provided for the 89626A board, I was wondering if you can provide the video data lines for the older 88617A board.

marqs85, 2021-09-09:
Looking at 88617A schematics, video data should be available from 3D and 4D chips (alternatively from 3C and 4C). Even though 3D/4D pinout is suitable for the 2x5 headers, 89626A adapter may not fit physically as pitch of the chips is different to 89626A. Could you measure center-to-center distance from 3D to 4D, and do you know if there is a high-res picture from 88617A PCB anywhere?

README files seem to have an error since 89626A is the currently supported revision, but it seems it should be easy to tweak the adapter PCB for 88617A.

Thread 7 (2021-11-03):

CPS2 - Blue Issue

Anselmo2004, 2021-11-03:
Recently I moved over my Cps2 board into a custom case. I noticed now that my BLUE color is off, it's actually too strong. All the colors are present, just blue is really high, like if it's bleeding over into the red,white, green color bars. I'll upload a picture of the issue, but is there a way to adjust individual colors somehow? something I should check?

marqs85, 2021-11-03:
Sounds like one of the blue bit lines is stuck high / floating. Try checking that the socket (J1) is firmly connected to the board and respective header to MSM chip.

Anselmo2004, 2021-11-03:
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

Anselmo2004, 2021-11-03:
Thanks for the response. I've attached the pictures and I'll check your recommendations

Anselmo2004, 2021-11-03:
Checking J1 I found a bad solder joint on the connector when checking each leg for continuity to the chip. Reflowed it and it's back to looking crispy! Thanks for the help and for the work. Greetings from Bakersfield  California!

Closed 2021-11-03.

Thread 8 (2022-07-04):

Support for CPS 1.5 Q-Sound for Darksoft Multi Kit

lilo-san, 2022-07-04:
Currently this is probably the only missing bit to be able to make the ultimate CPS 1 console using this kit.

It is understandable that since the sound can come from either the A-Board or the B-Board when making the mod a switch to select the audio input for the DigitalAV board should be installed if need to avoid any interference.

marqs85, 2022-07-04:
I've already designed an updated cps1_adapter for this purpose, will publish it once testing has been completed.

zeldaconstruction, 2022-07-04:
Will be a new board or just an update? If is a new board where I can pre-order?

lilo-san, 2022-07-04:
Will be a new board or just an update? If is a new board where I can pre-order?

lilo-san, 2022-07-05:
Thanks for your quick response. If you made the adapter available for preorder please let me know.

lilo-san, 2022-07-06:
Thanks for your quick response.

I will be waiting eagerly the update!

lilo-san, 2022-08-11:
Any progress on the new cps1_adapter? Any news would be appreciated.

marqs85, 2022-08-11:
I've not yet heard back from the person doing a test installation. I can share the design if you want to try yourself, but I can't guarantee its functionality.

lilo-san, 2022-08-14:
I understand, maybe we can follow up this conversation on mail? lilo@lilo-co.almostmy.com

marqs85, 2024-04-02:
This is now implemented in 6a7bf66bc1a7d012b20e8fcaaf8c5535ed85acb9

Closed 2024-04-02.

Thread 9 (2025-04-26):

No digital audio

DoctorDan1986, 2025-04-26:
I've installed this on an AES3-6 with perfect video results, but the audio board does not produce any audio through HDMI.  I'm a little put out and could use some advice.

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

DoctorDan1986, 2025-04-26:
I am forced to use the front headphone jack and override the audio input on my RT4K.

marqs85, 2025-05-04:
Apparently this was [resolved](https://videogameperfection.com/forums/topic/neo-geo-install-but-no-audio/#post-65841), assuming the post is about same installation.

Closed 2025-05-04.

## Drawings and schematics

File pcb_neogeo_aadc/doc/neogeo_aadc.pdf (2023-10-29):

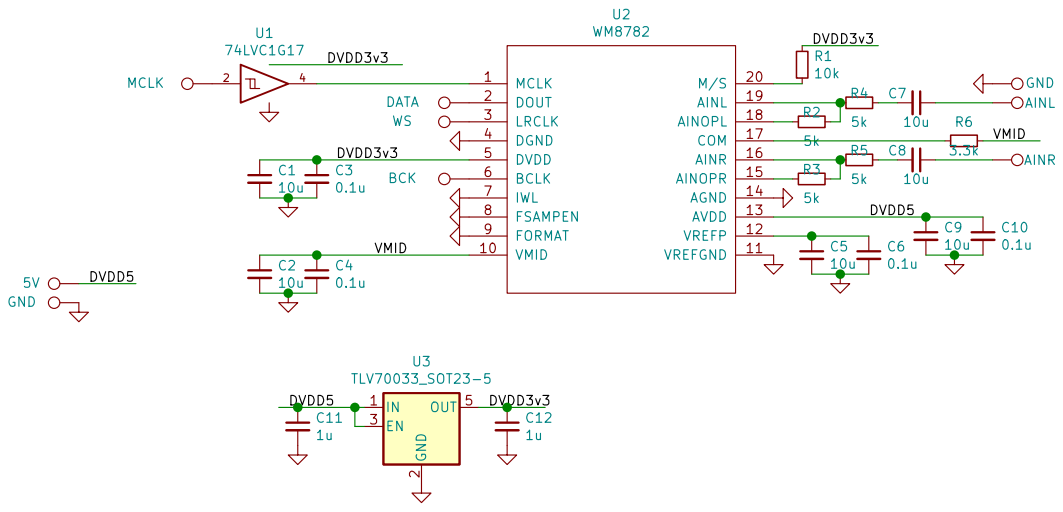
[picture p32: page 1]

File: neogeo_aadc.sch Sheet: /
Id: 1/1 Title: cps2_digiav audio ADC adapter

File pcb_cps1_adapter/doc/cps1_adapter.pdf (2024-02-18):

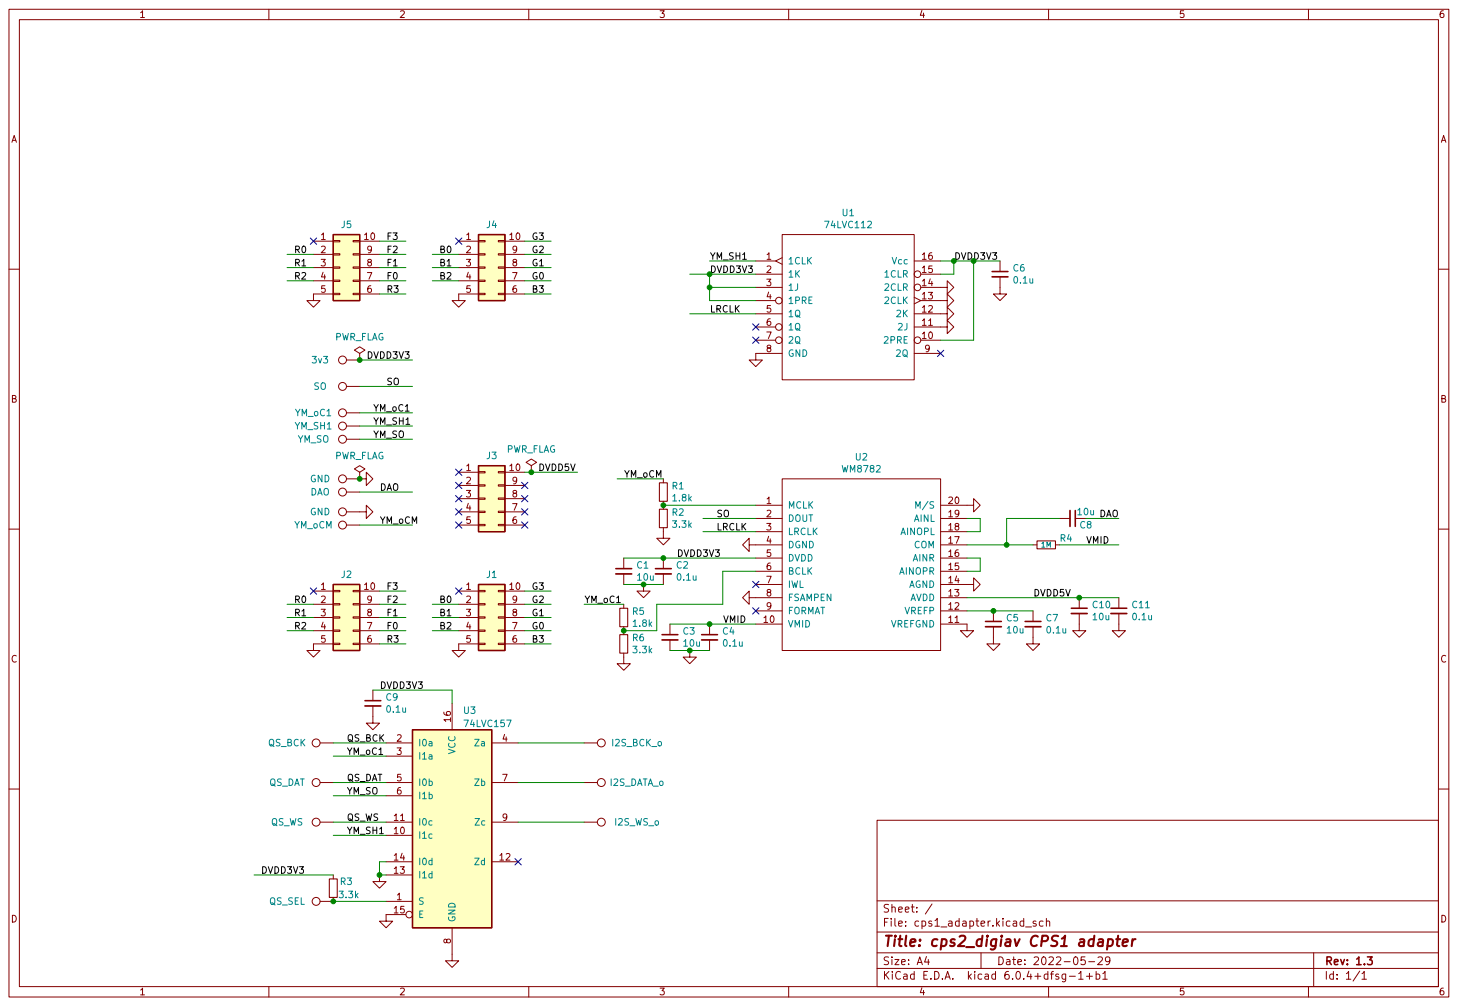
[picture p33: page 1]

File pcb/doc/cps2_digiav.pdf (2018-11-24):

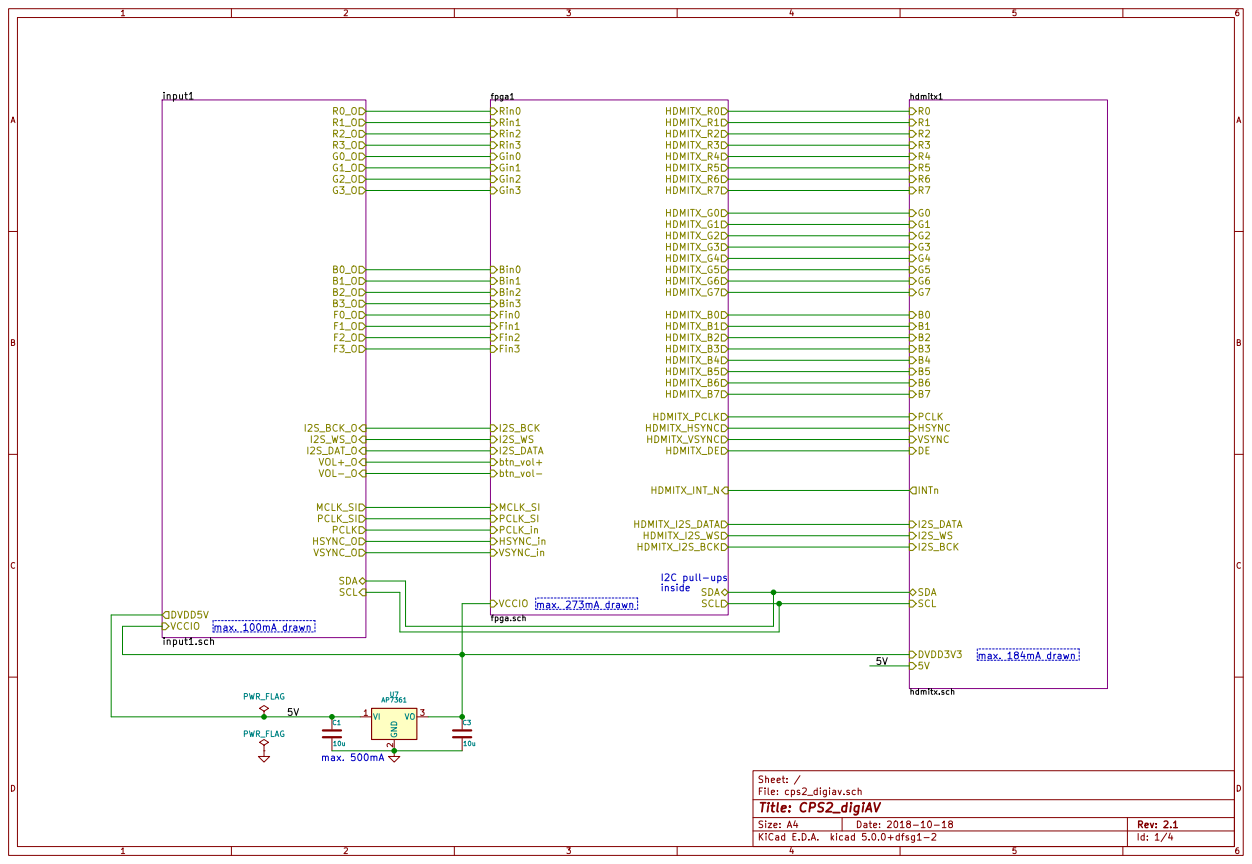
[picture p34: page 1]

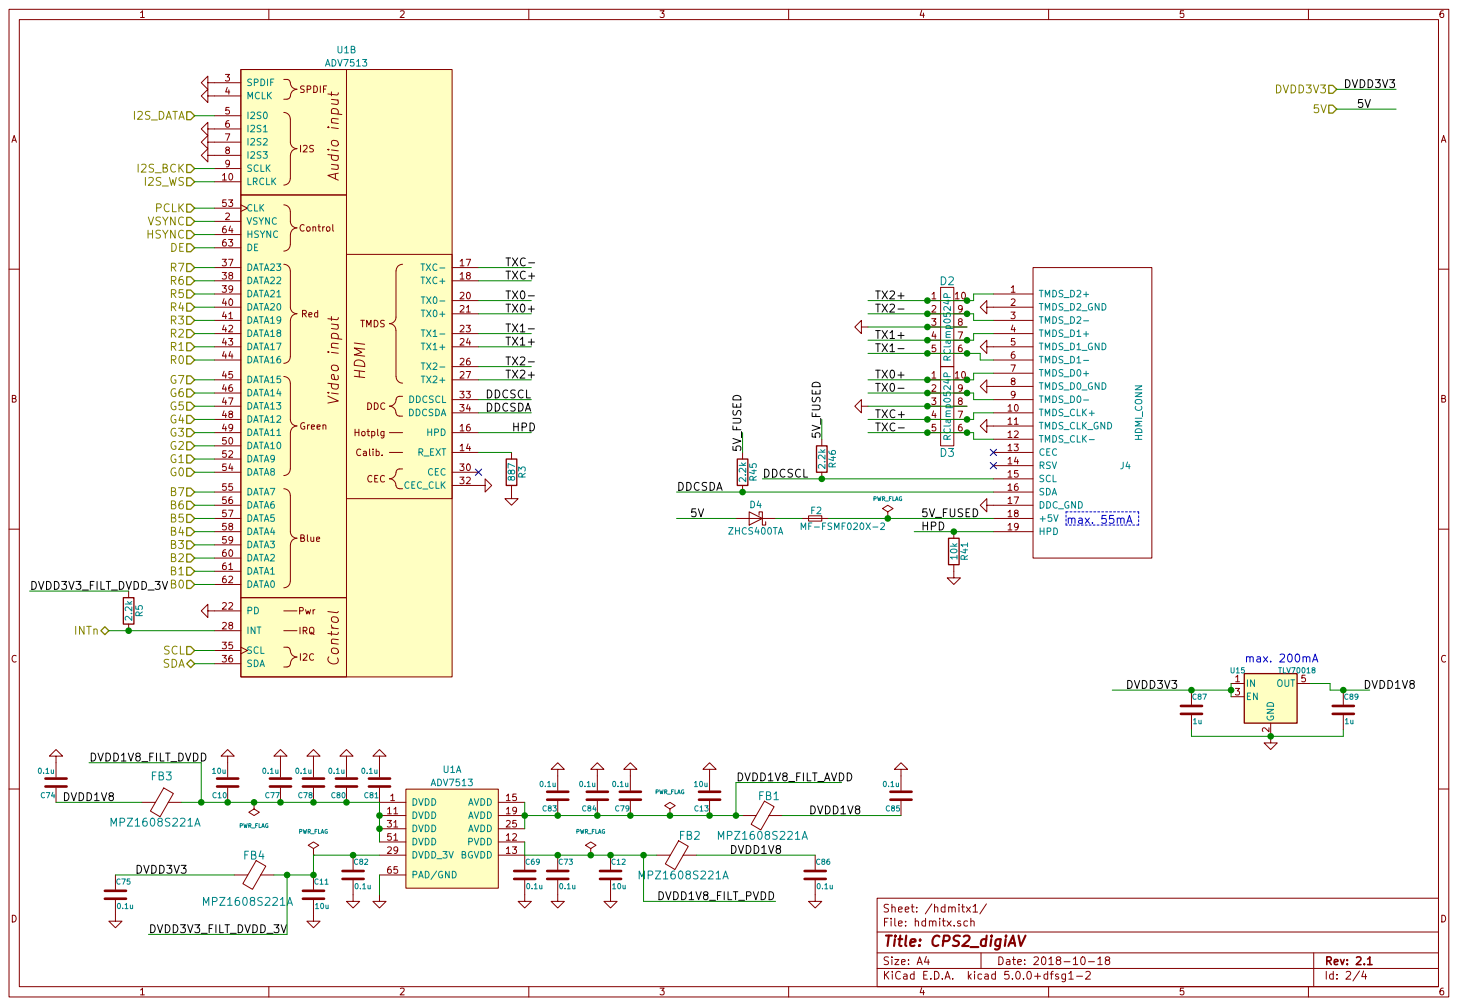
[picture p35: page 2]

File: hdmitx.sch Sheet: /hdmitx1/
Id: 2/4 Title: CPS2_digiAV

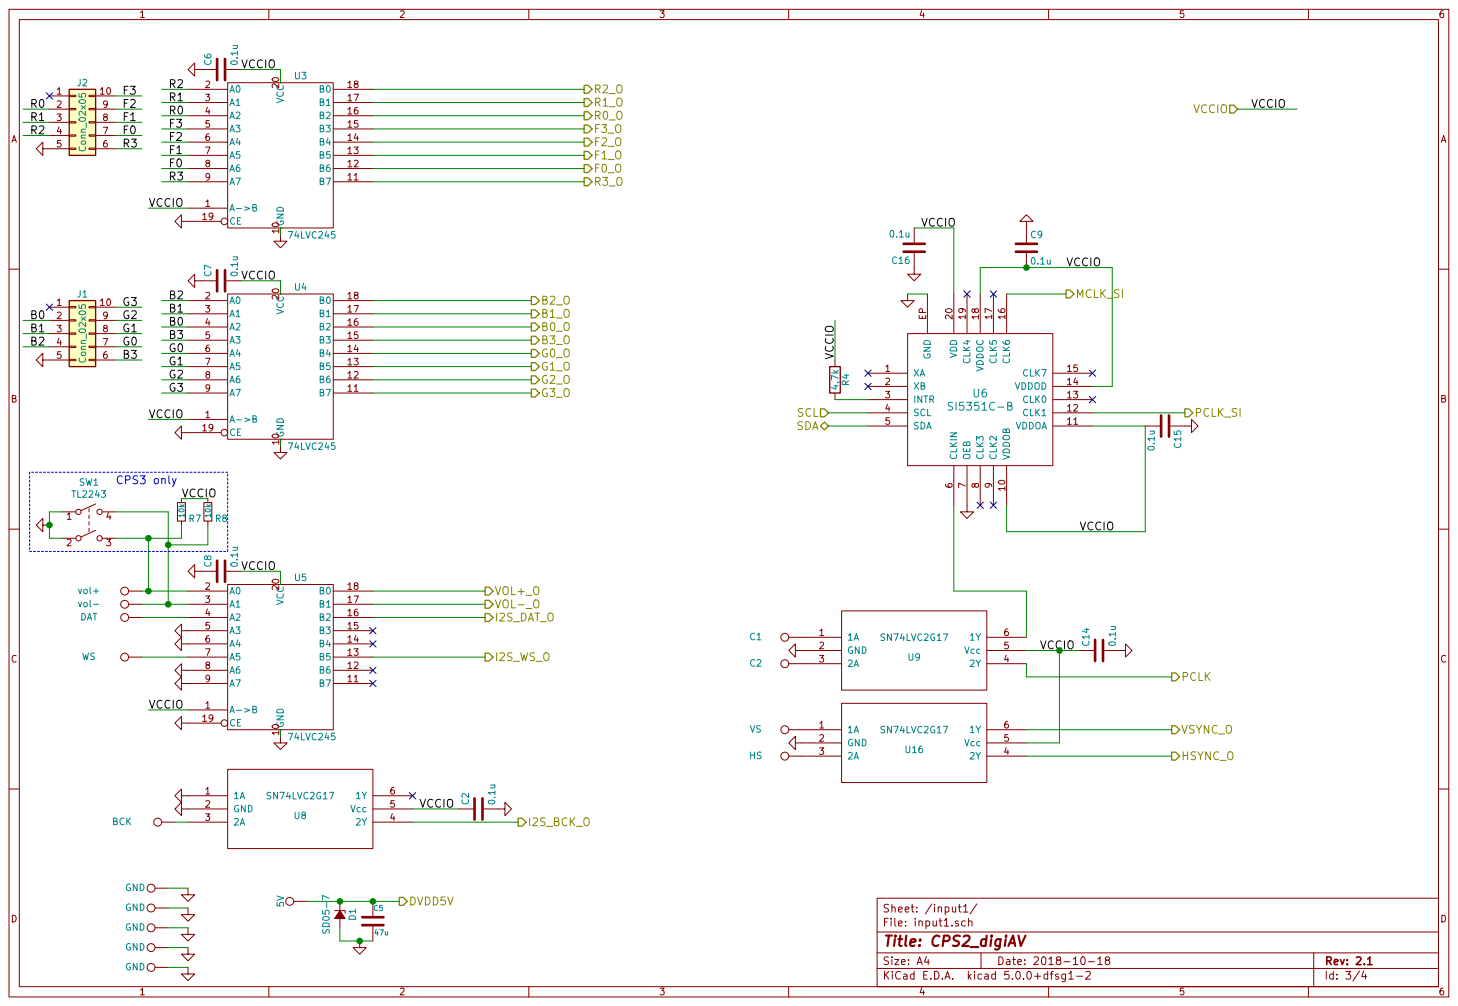
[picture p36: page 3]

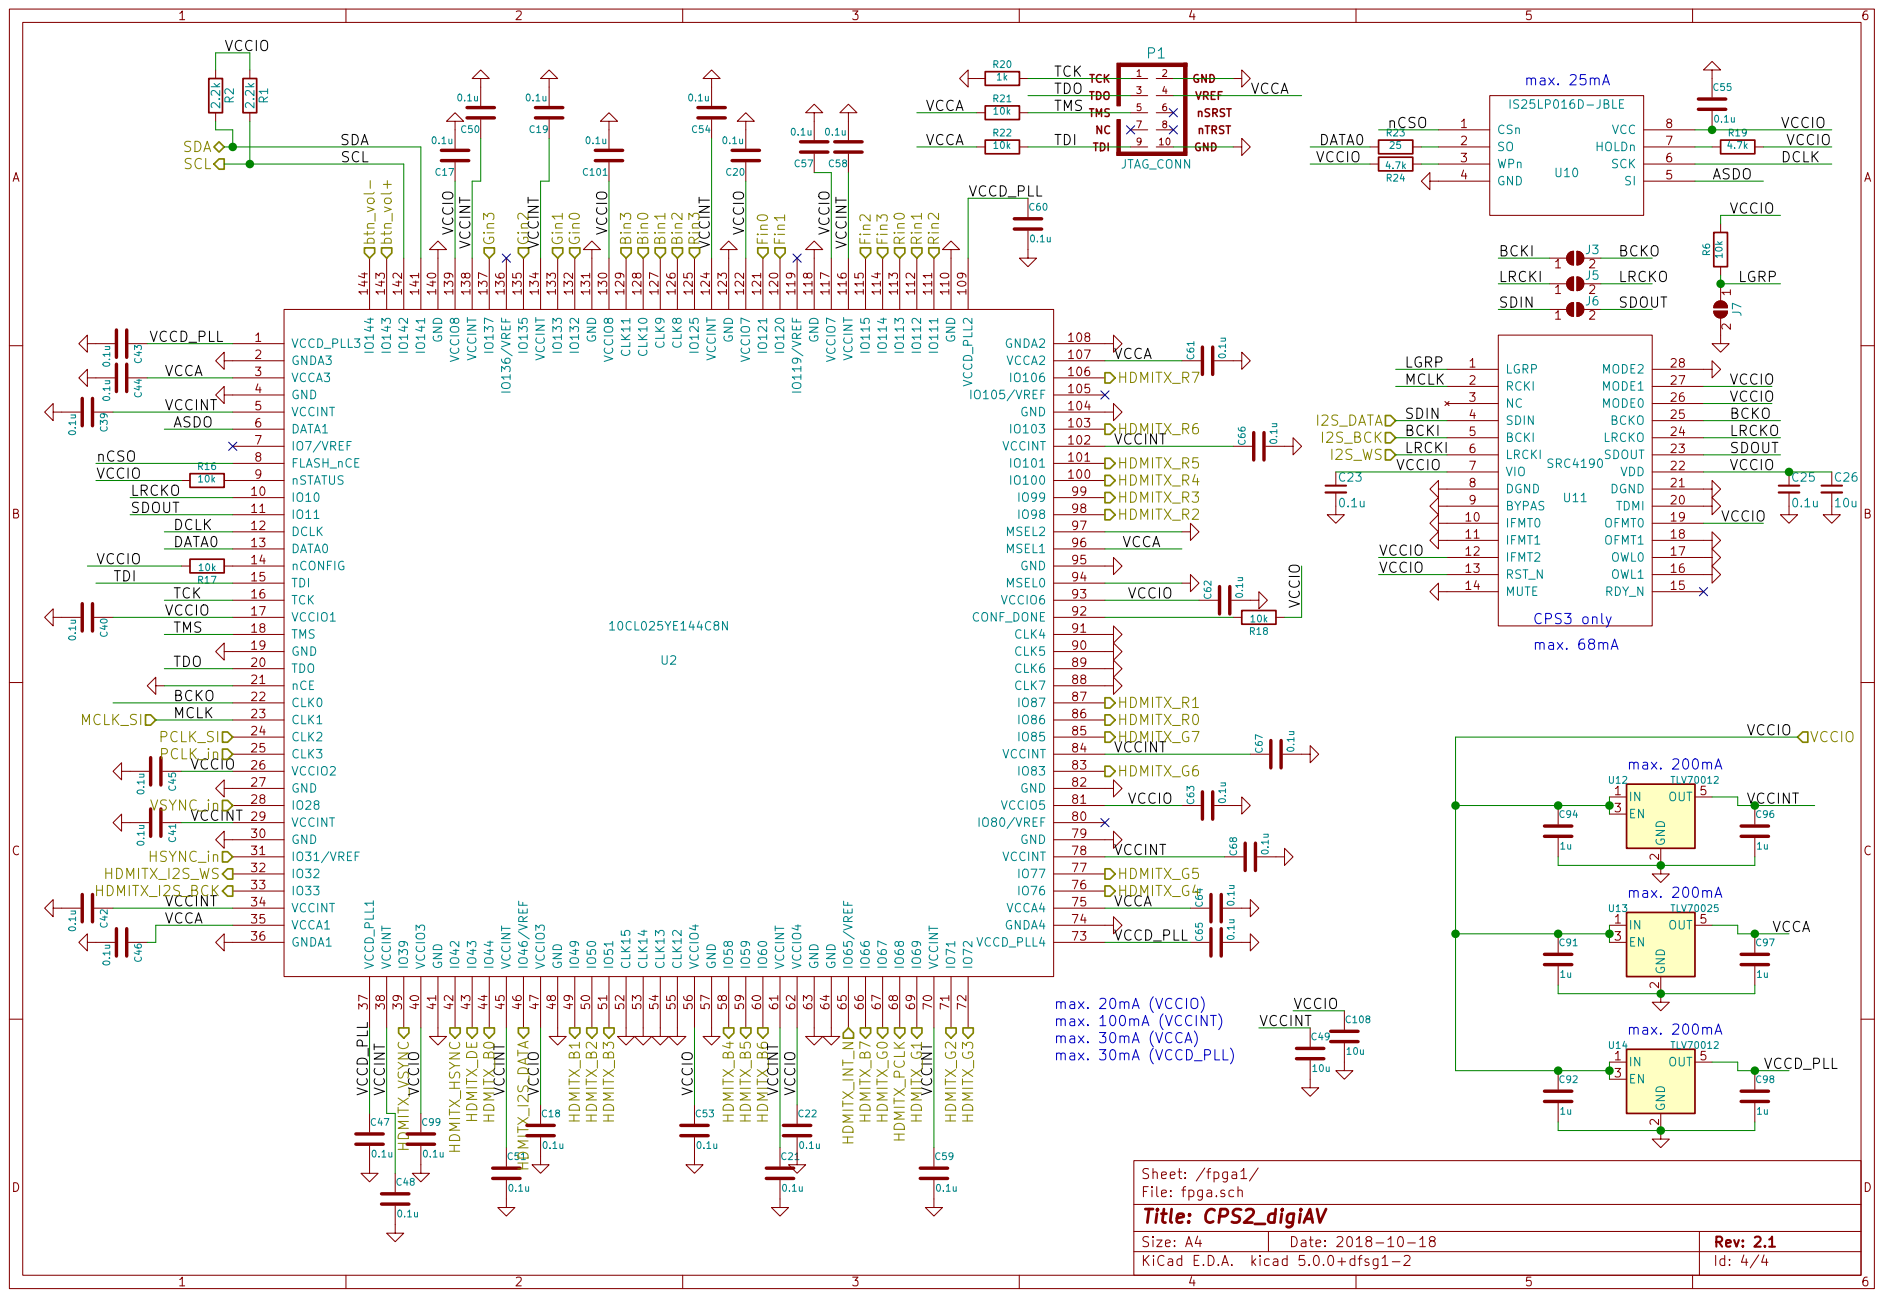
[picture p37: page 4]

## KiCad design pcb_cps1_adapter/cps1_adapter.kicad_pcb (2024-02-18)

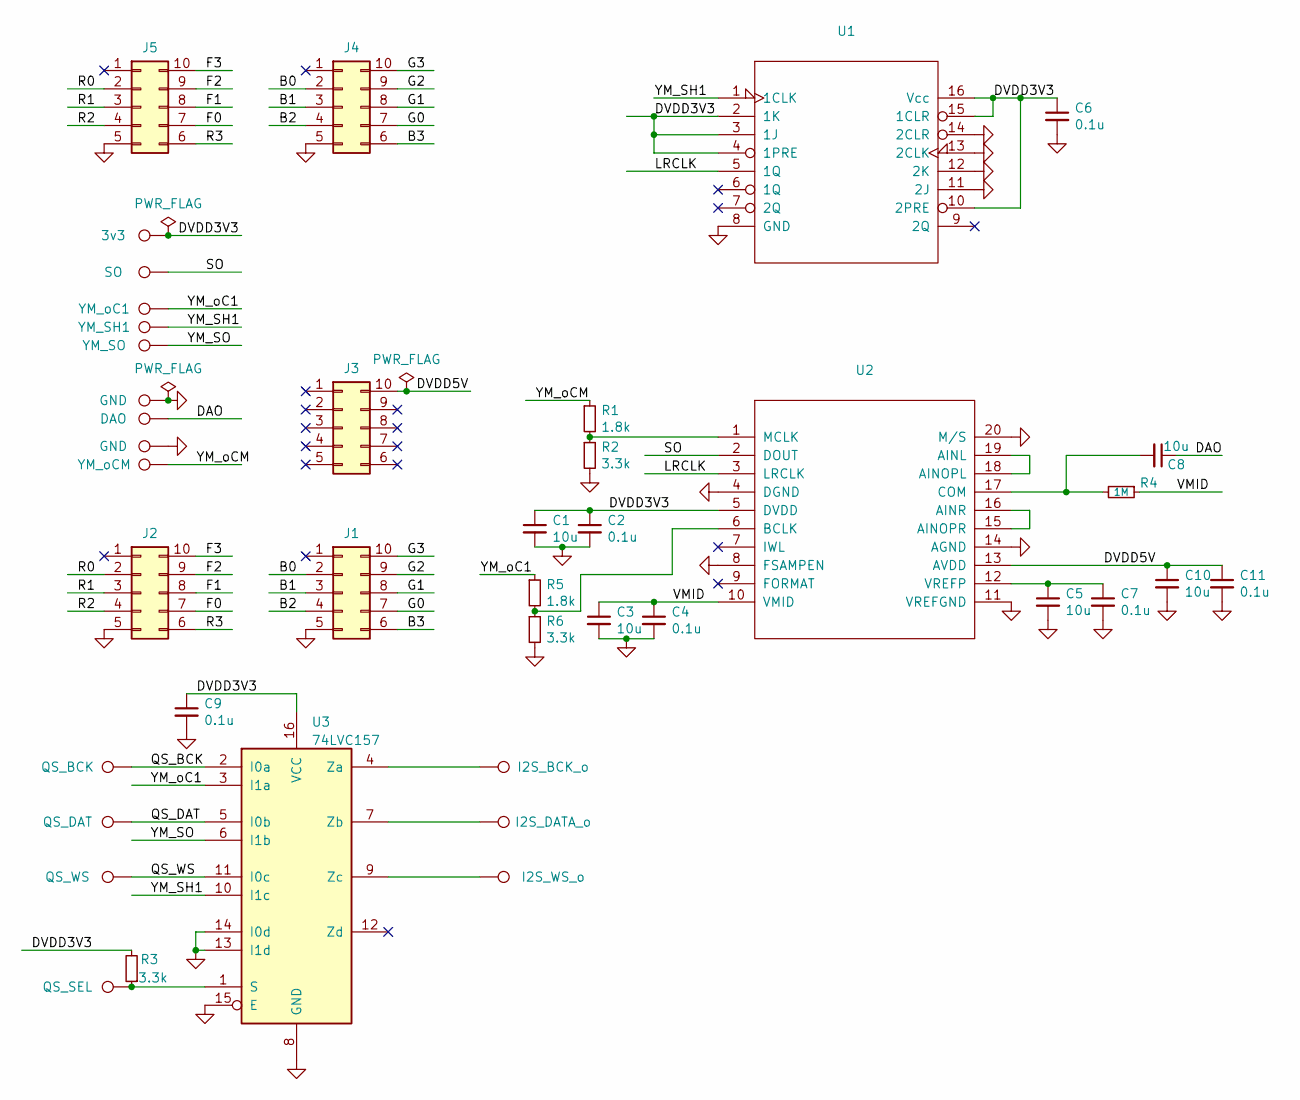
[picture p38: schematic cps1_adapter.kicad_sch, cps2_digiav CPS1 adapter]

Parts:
C1, C3, C5, C8, C10: 10u; SM0603_Capa_libcms
C2, C4, C6, C7, C9, C11: 0.1u; SM0603_Capa_libcms
J1, J2, J3, J4, J5: Conn_02x05_Counter_Clockwise; HLE-105-02-G-DV-PE
R1, R5: 1.8k; SM0603_Resistor_libcms
R2, R3, R6: 3.3k; SM0603_Resistor_libcms
R4: 1M; SM0603_Resistor_libcms
TP1, TP8: GND; SMD_PAD
TP2: DAO; SMD_PAD
TP3: 3v3; SMD_PAD
TP4: SO; SMD_PAD
TP5: YM_SO; SMD_PAD
TP6: YM_oC1; SMD_PAD
TP7: YM_SH1; SMD_PAD
TP9: YM_oCM; SMD_PAD
TP10: I2S_BCK_o; SMD_PAD
TP11: I2S_DATA_o; SMD_PAD
TP12: I2S_WS_o; SMD_PAD
TP13: QS_BCK; SMD_PAD
TP14: QS_DAT; SMD_PAD
TP15: QS_WS; SMD_PAD
TP16: QS_SEL; SMD_PAD
U1, U2: (no value)
U3: 74LVC157; SOIC-16_3.9x9.9mm_P1.27mm

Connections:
/B0: J1.2, J4.2
/B1: J1.3, J4.3
/B2: J1.4, J4.4
/B3: J1.6, J4.6
/DAO: C8.1, TP2.1
/DVDD3V3: C1.1, C2.1, C6.1, C9.1, R3.2, TP3.1, U1.2 (1K), U1.3 (1J), U1.4 (1PRE), U1.10 (2PRE), U1.15 (1CLR), U1.16 (Vcc), U2.5 (DVDD), U3.16 (VCC)
/DVDD5V: C10.1, C11.1, J3.10, U2.13 (AVDD)
/F0: J2.7, J5.7
/F1: J2.8, J5.8
/F2: J2.9, J5.9
/F3: J2.10, J5.10
/G0: J1.7, J4.7
/G1: J1.8, J4.8
/G2: J1.9, J4.9
/G3: J1.10, J4.10
/LRCLK: U1.5 (1Q), U2.3 (LRCLK)
/QS_BCK: TP13.1, U3.2 (I0a)
/QS_DAT: TP14.1, U3.5 (I0b)
/QS_WS: TP15.1, U3.11 (I0c)
/R0: J2.2, J5.2
/R1: J2.3, J5.3
/R2: J2.4, J5.4
/R3: J2.6, J5.6
/SO: TP4.1, U2.2 (DOUT)
/VMID: C3.1, C4.1, R4.1, U2.10 (VMID)
/YM_SH1: TP7.1, U1.1 (1CLK), U3.10 (I1c)
/YM_SO: TP5.1, U3.6 (I1b)
/YM_oC1: R5.1, TP6.1, U3.3 (I1a)
/YM_oCM: R1.1, TP9.1
GND: C1.2, C2.2, C3.2, C4.2, C5.2, C6.2, C7.2, C9.2, C10.2, C11.2, J1.5, J2.5, J4.5, J5.5, R2.2, R6.2, TP1.1, TP8.1, U1.8 (GND), U1.11 (2J), U1.12 (2K), U1.13 (2CLK), U1.14 (2CLR), U2.4 (DGND), U2.8 (FSAMPEN), U2.11 (VREFGND), U2.14 (AGND), U2.20 (M/S), U3.8 (GND), U3.13 (I1d), U3.14 (I0d), U3.15 (E)
unnamed: C5.1, C7.1, U2.12 (VREFP)
unnamed: C8.2, R4.2, U2.17 (COM)
unnamed: R1.2, R2.1, U2.1 (MCLK)
unnamed: R3.1, TP16.1, U3.1 (S)
unnamed: R5.2, R6.1, U2.6 (BCLK)
unnamed: TP10.1, U3.4 (Za)
unnamed: TP11.1, U3.7 (Zb)
unnamed: TP12.1, U3.9 (Zc)
unnamed: U2.15 (AINOPR), U2.16 (AINR)
unnamed: U2.18 (AINOPL), U2.19 (AINL)

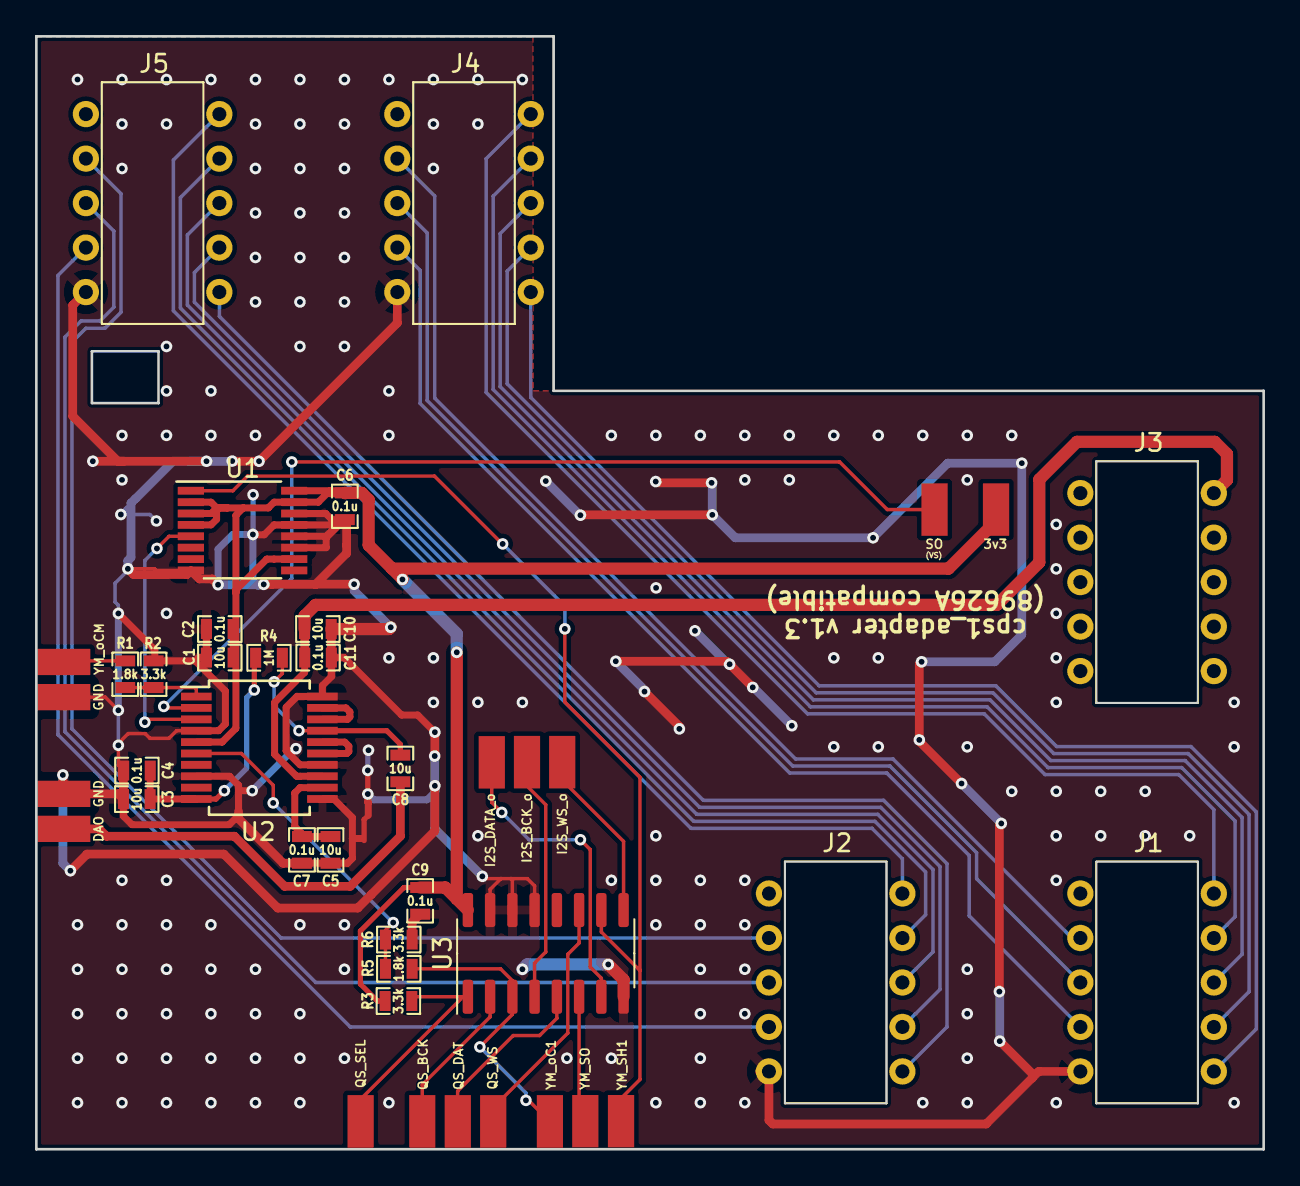
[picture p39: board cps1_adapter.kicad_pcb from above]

Board: 2 copper layers, 70.1 x 63.5 mm, 41 parts (0 on the bottom side), 40 nets.

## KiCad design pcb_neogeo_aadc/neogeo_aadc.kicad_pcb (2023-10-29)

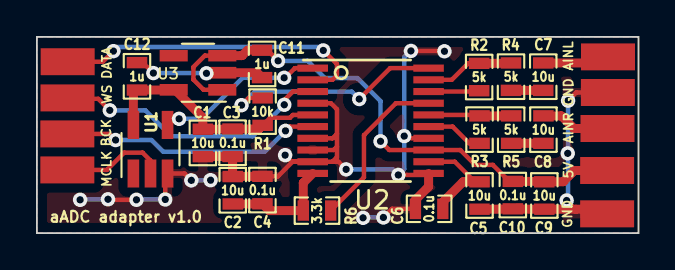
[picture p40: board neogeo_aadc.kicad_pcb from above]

Board: 2 copper layers, 33.4 x 10.9 mm, 30 parts (0 on the bottom side), 20 nets.

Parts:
C1, C2, C5, C7, C8, C9: 10u; SM0603_Capa_libcms
C3, C4, C6, C10: 0.1u; SM0603_Capa_libcms
C11, C12: 1u; SM0603_Capa_libcms
R1: 10k; SM0603_Resistor_libcms
R2, R3, R4, R5: 5k; SM0603_Resistor_libcms
R6: 3.3k; SM0603_Resistor_libcms
TP1: 5V; SMD_PAD
TP2, TP7: GND; SMD_PAD
TP3: MCLK; SMD_PAD
TP4: DATA; SMD_PAD
TP5: WS; SMD_PAD
TP6: BCK; SMD_PAD
TP8: AINL; SMD_PAD
TP9: AINR; SMD_PAD
U1: 74LVC1G17; SOT-23-5_HandSoldering
U2: WM8782; TSSOP-20_4.4x6.5mm_Pitch0.65mm_Handsoldering
U3: TLV70033_SOT23-5; SOT-23-5_HandSoldering

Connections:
/DVDD5: C9.1, C10.1, C11.1, TP1.1, U2.13, U3.1, U3.3
/VMID: C2.1, C4.1, R6.1, U2.10
GND: C1.2, C2.2, C3.2, C4.2, C5.2, C6.2, C9.2, C10.2, C11.2, C12.2, TP2.1, TP7.1, U1.3, U2.4, U2.7, U2.8, U2.9, U2.11, U2.14, U3.2
unnamed: C5.1, C6.1, U2.12
unnamed: C7.1, TP8.1
unnamed: C7.2, R4.1
unnamed: C8.1, TP9.1
unnamed: C8.2, R5.1
unnamed: R1.2, U2.20
unnamed: R2.1, R4.2, U2.19
unnamed: R2.2, U2.18
unnamed: R3.1, R5.2, U2.16
unnamed: R3.2, U2.15
unnamed: R6.2, U2.17
unnamed: TP3.1, U1.2
unnamed: TP4.1, U2.2
unnamed: TP5.1, U2.3
unnamed: TP6.1, U2.6
unnamed: U1.4, U2.1
VCC: C1.1, C3.1, C12.1, R1.1, U1.5, U2.5, U3.5

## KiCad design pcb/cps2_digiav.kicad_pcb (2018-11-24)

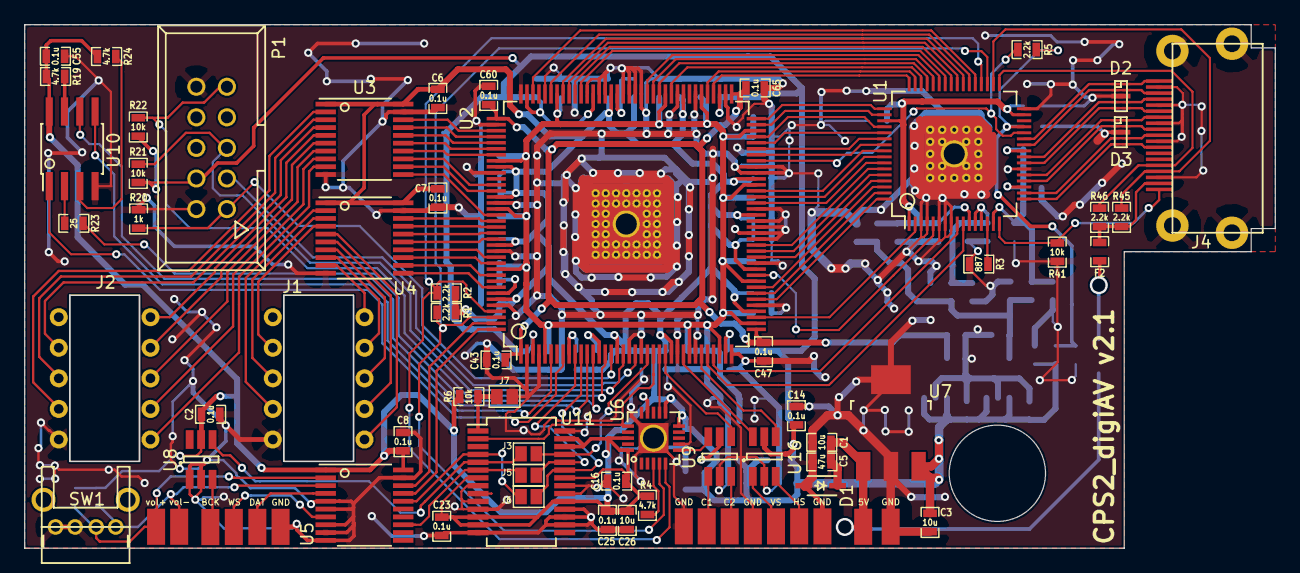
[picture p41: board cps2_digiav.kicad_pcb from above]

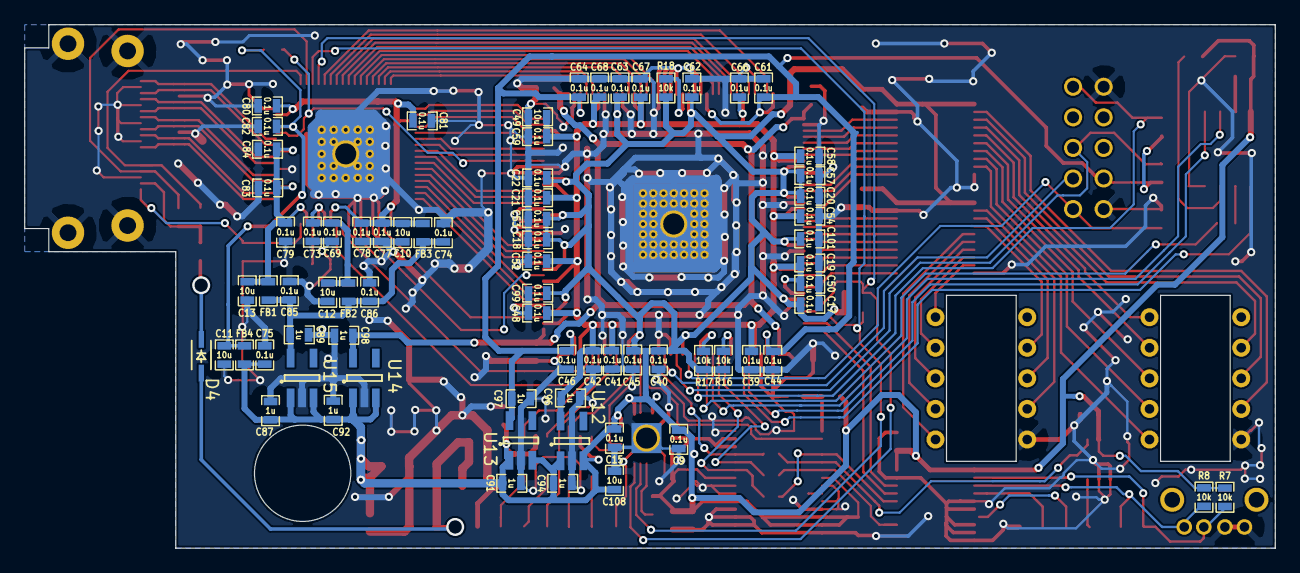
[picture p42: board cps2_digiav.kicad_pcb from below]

Board: 2 copper layers, 103.9 x 43.5 mm, 146 parts (74 on the bottom side), 130 nets.

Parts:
C1, C3, C10, C11, C12, C13, C26, C49, C108: 10u; SM0603_Capa_libcms
C2, C6, C7, C8, C9, C14, C15, C16, C17, C18, C19, C20, C21, C22, C23, C25, C39, C40, C41, C42, C43, C44, C45, C46, C47, C48, C50, C51, C53, C54, C55, C57, C58, C59, C60, C61, C62, C63, C64, C65, C66, C67, C68, C69, C73, C74, C75, C77, C78, C79, C80, C81, C82, C83, C84, C85, C86, C99, C101: 0.1u; SM0603_Capa_libcms
C5: 47u; SM0603_Capa_libcms
C87, C89, C91, C92, C94, C96, C97, C98: 1u; SM0603_Capa_libcms
D1: SD05-7; SOD-323_Handsoldering
D2, D3: RClamp0524P; SLP2510P8
D4: ZHCS400TA; SOD-323_Handsoldering
F2: MF-FSMF020X-2; SM0603_Resistor_libcms
FB1, FB2, FB3, FB4: MPZ1608S221A; SM0603_Resistor_libcms
J1, J2: Conn_02x05; HLE-105-02-G-DV-PE
J3, J5, J6, J7: GS2
J4: HDMI_CONN; HDMI_CONN-10029449-111RLF
P1: JTAG_CONN; VASCH5x2
R1, R2, R5, R45, R46: 2.2k; SM0603_Resistor_libcms
R3: 887; SM0603_Resistor_libcms
R4, R19, R24: 4.7k; SM0603_Resistor_libcms
R6, R7, R8, R16, R17, R18, R21, R22, R41: 10k; SM0603_Resistor_libcms
R20: 1k; SM0603_Resistor_libcms
R23: 25; SM0603_Resistor_libcms
SW1: TL2243
U1: ADV7513; LQFP-64-1EP_10x10mm_Pitch0.5mm_Handsoldering
U2: 10CL025YE144C8N; TQFP-144_thermal
U3, U4, U5: 74LVC245; TSSOP-20_4.4x6.5mm_Pitch0.65mm_Handsoldering
U6: SI5351C-B; QFN-20-1EP_4x4mm_Pitch0.5mm_Handsoldering
U7: AP7361; SOT-223_Handsoldering
U8, U9, U16: SN74LVC2G17; SOT-23-6_Handsoldering
U10: IS25LP016D-JBLE; SOIC-8_3.9x4.9mm_Pitch1.27mm_Handsoldering
U11: SRC4190; SSOP-28_5.3x10.2mm_Pitch0.65mm
U12, U14: TLV70012; SOT-23-5_Handsoldering
U13: TLV70025; SOT-23-5_Handsoldering
U15: TLV70018; SOT-23-5_Handsoldering
W1: 5V; SMD_PAD
W2: BCK; SMD_PAD
W3: WS; SMD_PAD
W4: DAT; SMD_PAD
W5: vol+; SMD_PAD
W6: vol-; SMD_PAD
W7, W8, W9, W10, W14: GND; SMD_PAD
W11: HS; SMD_PAD
W12: VS; SMD_PAD
W13: C2; SMD_PAD
W15: C1; SMD_PAD

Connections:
/5V: C1.1, C5.1, D1.1, D4.2, U7.1, W1.1
/fpga1/ASDO: U2.6, U10.5
/fpga1/BCKO: J3.2, U2.22, U11.25
/fpga1/DATA0: R23.1, U2.13
/fpga1/DCLK: U2.12, U10.6
/fpga1/HDMITX_HSYNC: U1.64, U2.42
/fpga1/HDMITX_I2S_BCK: U1.9, U2.33
/fpga1/HDMITX_I2S_DATA: U1.5, U2.46
/fpga1/HDMITX_I2S_WS: U1.10, U2.32
/fpga1/HDMITX_INT_N: R5.2, U1.28, U2.65
/fpga1/HDMITX_PCLK: U1.53, U2.68
/fpga1/HDMITX_R0: U1.44, U2.86
/fpga1/HDMITX_R1: U1.43, U2.87
/fpga1/HDMITX_R2: U1.42, U2.98
/fpga1/HDMITX_R3: U1.41, U2.99
/fpga1/HDMITX_R4: U1.40, U2.100
/fpga1/HDMITX_R5: U1.39, U2.101
/fpga1/HDMITX_R6: U1.38, U2.103
/fpga1/HDMITX_R7: U1.37, U2.106
/fpga1/HDMITX_VSYNC: U1.2, U2.39
/fpga1/I2S_BCK: J3.1, U8.4, U11.5
/fpga1/I2S_DATA: J6.1, U5.16, U11.4
/fpga1/I2S_WS: J5.1, U5.13, U11.6
/fpga1/LGRP: J7.1, R6.1, U11.1
/fpga1/LRCKO: J5.2, U2.10, U11.24
/fpga1/MCLK_SI: U2.23, U6.16, U11.2
/fpga1/PCLK_SI: U2.24, U6.12
/fpga1/SCL: R1.2, U1.35, U2.142, U6.4
/fpga1/SDA: R2.2, U1.36, U2.141, U6.5
/fpga1/SDOUT: J6.2, U2.11, U11.23
/fpga1/TCK: P1.1, R20.2, U2.16
/fpga1/TDI: P1.9, R22.2, U2.15
/fpga1/TDO: P1.3, U2.20
/fpga1/TMS: P1.5, R21.2, U2.18
/fpga1/VCCA: C44.1, C46.1, C61.1, C64.1, C97.1, P1.4, R21.1, R22.1, U2.3, U2.35, U2.75, U2.96, U2.107, U13.5
/fpga1/VCCD_PLL: C43.1, C47.1, C60.1, C65.1, C98.1, U2.1, U2.37, U2.73, U2.109, U14.5
/fpga1/VCCINT: C19.1, C21.1, C39.1, C41.1, C42.1, C48.1, C49.1, C50.1, C51.1, C54.1, C58.1, C59.1, C66.1, C67.1, C68.1, C96.1, U2.5, U2.29, U2.34, U2.38, U2.45, U2.61, U2.70, U2.78, U2.84, U2.102, U2.116, U2.124, U2.134, U2.138, U12.5
/fpga1/nCSO: U2.8, U10.1
/hdmitx1/5V_FUSED: F2.2, J4.18, R45.1, R46.1
/hdmitx1/B0: U1.62, U2.44
/hdmitx1/B1: U1.61, U2.49
/hdmitx1/B2: U1.60, U2.50
/hdmitx1/B3: U1.59, U2.51
/hdmitx1/B4: U1.58, U2.58
/hdmitx1/B5: U1.57, U2.59
/hdmitx1/B6: U1.56, U2.60
/hdmitx1/B7: U1.55, U2.66
/hdmitx1/DDCSCL: J4.15, R46.2, U1.33
/hdmitx1/DDCSDA: J4.16, R45.2, U1.34
/hdmitx1/DE: U1.63, U2.43
/hdmitx1/DVDD1V8: C74.1, C85.1, C86.1, C89.1, FB1.1, FB2.1, FB3.2, U15.5
/hdmitx1/DVDD1V8_FILT_AVDD: C13.1, C79.1, C83.1, C84.1, FB1.2, U1.15, U1.19, U1.25
/hdmitx1/DVDD1V8_FILT_DVDD: C10.1, C77.1, C78.1, C80.1, C81.1, FB3.1, U1.1, U1.11, U1.31, U1.51
/hdmitx1/DVDD1V8_FILT_PVDD: C12.1, C69.1, C73.1, FB2.2, U1.12, U1.13
/hdmitx1/DVDD3V3: C2.1, C3.1, C6.2, C7.2, C8.2, C9.2, C14.1, C15.2, C16.2, C17.1, C18.1, C20.1, C22.1, C23.1, C25.1, C26.1, C40.1, C45.1, C53.1, C55.2, C57.1, C62.1, C63.1, C75.1, C87.1, C91.1, C92.1, C94.1, C99.1, C101.1, C108.1, FB4.2, R1.1, R2.1, R4.1, R6.2, R7.1, R8.1, R16.1, R17.2, R18.1, R19.2, R24.2, U2.17, U2.26, U2.40, U2.47, U2.56, U2.62, U2.81, U2.93, U2.117, U2.122, U2.130, U2.139, U3.1, U3.20, U4.1, U4.20, U5.1, U5.20, U6.10, U6.11, U6.14, U6.18, U6.20, U7.3, U8.5, U9.5, U10.8, U11.7, U11.12, U11.13, U11.19, U11.22, U11.26, U11.27, U12.1, U12.3, U13.1, U13.3, U14.1, U14.3, U15.1, U15.3, U16.5
/hdmitx1/DVDD3V3_FILT_DVDD_3V: C11.1, C82.1, FB4.1, R5.1, U1.29
/hdmitx1/G0: U1.54, U2.67
/hdmitx1/G1: U1.52, U2.69
/hdmitx1/G2: U1.50, U2.71
/hdmitx1/G3: U1.49, U2.72
/hdmitx1/G4: U1.48, U2.76
/hdmitx1/G5: U1.47, U2.77
/hdmitx1/G6: U1.46, U2.83
/hdmitx1/G7: U1.45, U2.85
/hdmitx1/HPD: J4.19, R41.1, U1.16
/hdmitx1/TX0+: D3.1, D3.10, J4.7, U1.21
/hdmitx1/TX0-: D3.2, D3.9, J4.9, U1.20
/hdmitx1/TX1+: D2.4, D2.7, J4.4, U1.24
/hdmitx1/TX1-: D2.5, D2.6, J4.6, U1.23
/hdmitx1/TX2+: D2.1, D2.10, J4.1, U1.27
/hdmitx1/TX2-: D2.2, D2.9, J4.3, U1.26
/hdmitx1/TXC+: D3.4, D3.7, J4.10, U1.18
/hdmitx1/TXC-: D3.5, D3.6, J4.12, U1.17
/input1/B0: J1.2, U4.4
/input1/B0_O: U2.128, U4.16
/input1/B1: J1.3, U4.3
/input1/B1_O: U2.127, U4.17
/input1/B2: J1.4, U4.2
/input1/B2_O: U2.126, U4.18
/input1/B3: J1.6, U4.5
/input1/B3_O: U2.129, U4.15
/input1/F0: J2.7, U3.8
/input1/F0_O: U2.121, U3.12
/input1/F1: J2.8, U3.7
/input1/F1_O: U2.120, U3.13
/input1/F2: J2.9, U3.6
/input1/F2_O: U2.115, U3.14
/input1/F3: J2.10, U3.5
/input1/F3_O: U2.114, U3.15
/input1/G0: J1.7, U4.6
/input1/G0_O: U2.132, U4.14
/input1/G1: J1.8, U4.7
/input1/G1_O: U2.133, U4.13
/input1/G2: J1.9, U4.8
/input1/G2_O: U2.135, U4.12
/input1/G3: J1.10, U4.9
/input1/G3_O: U2.137, U4.11
/input1/HSYNC_O: U2.31, U16.4
/input1/PCLK: U2.25, U9.4
/input1/R0: J2.2, U3.4
/input1/R0_O: U2.113, U3.16
/input1/R1: J2.3, U3.3
/input1/R1_O: U2.112, U3.17
/input1/R2: J2.4, U3.2
/input1/R2_O: U2.111, U3.18
/input1/R3: J2.6, U3.9
/input1/R3_O: U2.125, U3.11
/input1/VOL+_O: U2.143, U5.18
/input1/VOL-_O: U2.144, U5.17
/input1/VSYNC_O: U2.28, U16.6
GND: C1.2, C2.2, C3.2, C5.2, C6.1, C7.1, C8.1, C9.1, C10.2, C11.2, C12.2, C13.2, C14.2, C15.1, C16.1, C17.2, C18.2, C19.2, C20.2, C21.2, C22.2, C23.2, C25.2, C26.2, C39.2, C40.2, C41.2, C42.2, C43.2, C44.2, C45.2, C46.2, C47.2, C48.2, C49.2, C50.2, C51.2, C53.2, C54.2, C55.1, C57.2, C58.2, C59.2, C60.2, C61.2, C62.2, C63.2, C64.2, C65.2, C66.2, C67.2, C68.2, C69.2, C73.2, C74.2, C75.2, C77.2, C78.2, C79.2, C80.2, C81.2, C82.2, C83.2, C84.2, C85.2, C86.2, C87.2, C89.2, C91.2, C92.2, C94.2, C96.2, C97.2, C98.2, C99.2, C101.2, C108.2, D1.2, D2.3, D2.8, D3.3, D3.8, J1.5, J2.5, J4.2, J4.5, J4.8, J4.11, J4.17, J7.2, P1.2, P1.10, R3.2, R20.1, R41.2, SW1.1, SW1.2, U1.3, U1.4, U1.6, U1.7, U1.8, U1.22, U1.32, U1.65, U2.2, U2.4, U2.19, U2.21, U2.27, U2.30, U2.36, U2.41, U2.48, U2.52, U2.53, U2.54, U2.55, U2.57, U2.63, U2.64, U2.74, U2.79, U2.82, U2.88, U2.89, U2.90, U2.91, U2.94, U2.95, U2.97, U2.104, U2.108, U2.110, U2.118, U2.123, U2.131, U2.140, U3.10, U3.19, U4.10, U4.19, U5.5, U5.6, U5.8, U5.9, U5.10, U5.19, U6.7, U6.EP, U7.2, U8.1, U8.2, U9.2, U10.4, U11.8, U11.9, U11.10, U11.11, U11.14, U11.16, U11.17, U11.18, U11.20, U11.21, U11.28, U12.2, U13.2, U14.2, U15.2, U16.2, W7.1, W8.1, W9.1, W10.1, W14.1
unnamed: D4.1, F2.1
unnamed: R3.1, U1.14
unnamed: R4.2, U6.3
unnamed: R7.2, SW1.3, U5.2, W5.1
unnamed: R8.2, SW1.4, U5.3, W6.1
unnamed: R16.2, U2.9
unnamed: R17.1, U2.14
unnamed: R18.2, U2.92
unnamed: R19.1, U10.7
unnamed: R23.2, U10.2
unnamed: R24.1, U10.3
unnamed: U5.4, W4.1
unnamed: U5.7, W3.1
unnamed: U6.6, U9.6
unnamed: U8.3, W2.1
unnamed: U9.1, W15.1
unnamed: U9.3, W13.1
unnamed: U16.1, W12.1
unnamed: U16.3, W11.1

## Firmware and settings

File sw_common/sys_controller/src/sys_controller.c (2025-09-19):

//
// Copyright (C) 2016-2020  Markus Hiienkari <mhiienka@niksula.hut.fi>
//
// This file is part of CPS2 Digital AV Interface project.
//
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

#include <stdio.h>
#include <unistd.h>
#include "system.h"
#include "string.h"
#include "altera_avalon_pio_regs.h"
#include "i2c_opencores.h"
#include "sysconfig.h"
#include "adv7513.h"
#include "si5351.h"
#include "sc_config_regs.h"
#include "osd_generator_regs.h"
#include "video_modes.h"
#include "avconfig.h"
#include "menu.h"
#include "flash.h"
#include "userdata.h"
#include "controls.h"

#define SSTAT_BTN_MASK  0xc0000000
#define SSTAT_BTN_OFFS  30

#define ADV7513_MAIN_BASE 0x72
#define ADV7513_EDID_BASE 0x7e
#define ADV7513_PKTMEM_BASE 0x70
#define ADV7513_CEC_BASE 0x78

#define SI5351_BASE (0xC0>>1)

si5351_dev si_dev = {.i2cm_base = I2C_OPENCORES_0_BASE,
                     .i2c_addr = SI5351_BASE,
                     .xtal_freq = 0LU};

adv7513_dev advtx_dev = {.i2cm_base = I2C_OPENCORES_0_BASE,
                         .main_base = ADV7513_MAIN_BASE,
                         .edid_base = ADV7513_EDID_BASE,
                         .pktmem_base = ADV7513_PKTMEM_BASE,
                         .cec_base = ADV7513_CEC_BASE};

flash_ctrl_dev flashctrl_dev = {.regs = (volatile gen_flash_if_regs*)INTEL_GENERIC_SERIAL_FLASH_INTERFACE_TOP_0_AVL_CSR_BASE,
                                .flash_size = 0x0200000};

volatile sc_regs *sc = (volatile sc_regs*)SC_CONFIG_0_BASE;
volatile osd_regs *osd = (volatile osd_regs*)OSD_GENERATOR_0_BASE;

input_mode_t input_mode;
extern uint8_t menu_active;


void update_osd_size(mode_data_t *vm_out) {
    uint8_t osd_size = vm_out->timings.v_active / 700;

    osd->osd_config.x_size = osd_size;
    osd->osd_config.y_size = osd_size;
}

void update_sc_config(mode_data_t *vm_in, mode_data_t *vm_out, vm_mult_config_t *vm_conf, avconfig_t *avc)
{
    int i;

    hv_config_reg hv_out_config = {.data=0x00000000};
    hv_config2_reg hv_out_config2 = {.data=0x00000000};
    hv_config3_reg hv_out_config3 = {.data=0x00000000};
    xy_config_reg xy_out_config = {.data=0x00000000};
    xy_config2_reg xy_out_config2 = {.data=0x00000000};
    misc_config_reg misc_config = {.data=0x00000000};
    sl_config_reg sl_config = {.data=0x00000000};
    sl_config2_reg sl_config2 = {.data=0x00000000};

    // Set output params
    hv_out_config.h_total = vm_out->timings.h_total;
    hv_out_config.h_active = vm_out->timings.h_active;
    hv_out_config.h_backporch = vm_out->timings.h_backporch;
    hv_out_config2.h_synclen = vm_out->timings.h_synclen;
    hv_out_config2.v_total = vm_out->timings.v_total;
    hv_out_config2.v_active = vm_out->timings.v_active;
    hv_out_config3.v_backporch = vm_out->timings.v_backporch;
    hv_out_config3.v_synclen = vm_out->timings.v_synclen;
    hv_out_config3.v_startline = vm_conf->framesync_line;

    xy_out_config.x_size = vm_conf->x_size;
    xy_out_config.y_size = vm_conf->y_size;
    xy_out_config.x_offset = vm_conf->x_offset;
    xy_out_config2.y_offset = vm_conf->y_offset;
    xy_out_config2.x_start_lb = vm_conf->x_start_lb;
    xy_out_config2.y_start_lb = vm_conf->y_start_lb;
    xy_out_config2.x_rpt = vm_conf->x_rpt;
    xy_out_config2.y_rpt = vm_conf->y_rpt;
    xy_out_config2.x_skip = vm_conf->x_skip;

    for (i=0; i<6; i++) {
        sl_config.sl_l_str_arr |= avc->sl_str<<(4*i);
        sl_config2.sl_c_str_arr |= avc->sl_str<<(4*i);
    }
    sl_config.sl_l_overlay = (avc->sl_mode >= 1) ? ((1<<((vm_conf->y_rpt+1)/2))-1) : 0;
    sl_config2.sl_c_overlay = (avc->sl_mode == 2) ? ((1<<((vm_conf->x_rpt+1)/3))-1) : 0;
    sl_config.sl_method = avc->sl_method;

    sc->hv_out_config = hv_out_config;
    sc->hv_out_config2 = hv_out_config2;
    sc->hv_out_config3 = hv_out_config3;
    sc->xy_out_config = xy_out_config;
    sc->xy_out_config2 = xy_out_config2;
    sc->misc_config = misc_config;
    sc->sl_config = sl_config;
    sc->sl_config2 = sl_config2;
}

// Initialize hardware
int init_hw()
{
    I2C_init(I2C_OPENCORES_0_BASE,ALT_CPU_FREQ, 400000);

    // init HDMI TX
    adv7513_init(&advtx_dev);

    // Init Si5351C
    si5351_init(&si_dev);

    set_default_avconfig(1);
    read_userdata(0);
    init_menu();

    // Init OSD
    osd->osd_config.x_offset = 3;
    osd->osd_config.y_offset = 3;
    osd->osd_config.enable = 1;
    osd->osd_config.status_timeout = 0;
    osd->osd_config.status_refresh = 0;
    osd->osd_config.menu_active = 0;
    osd->osd_config.border_color = 1;

    return 0;
}

int check_input_mode_change() {
    int mode_changed = 0;

    input_mode_t target_mode = {0};

    target_mode.h_active = sc->fe_status.h_active;
    target_mode.v_active = sc->fe_status.v_active;
    target_mode.vclks_per_frame = sc->fe_status2.vclks_per_frame;

    if (memcmp(&input_mode, &target_mode, sizeof(input_mode_t)))
        mode_changed = 1;

    memcpy(&input_mode, &target_mode, sizeof(input_mode_t));

    return mode_changed;
}

int main()
{
    int ret, input_mode_change;
    status_t status;
    mode_data_t vmode_in, vmode_out;
    vm_mult_config_t vm_conf;
    const ad_mode_data_t *output_mode;
    avconfig_t *cur_avconfig;

    uint32_t btn_vec, btn_vec_prev=0;
    uint8_t btn_rpt=0;

    // Write-protect flash
    flash_write_protect(&flashctrl_dev, 1);

    ret = init_hw();

    if (ret == 0) {
        printf("### cps2_digiAV INIT OK ###\n\n");
    } else {
        printf("Init error  %d", ret);
        while (1) {}
    }

    cur_avconfig = get_current_avconfig();

    while(1) {

        btn_vec = (~IORD_ALTERA_AVALON_PIO_DATA(PIO_0_BASE) & SSTAT_BTN_MASK) >> SSTAT_BTN_OFFS;

        if ((btn_vec != 0) && (btn_vec == btn_vec_prev))
            btn_rpt++;
        else
            btn_rpt = 0;

        if (btn_vec_prev == 0) {
            btn_vec_prev = btn_vec;
        } else {
            btn_vec_prev = btn_vec;
            btn_vec = 0;
        }

        if (!menu_active)
            btn_vec = (btn_rpt == 80) ? btn_vec_prev : 0;

        parse_control(btn_vec);

        status = update_avconfig(NULL);

        input_mode_change = check_input_mode_change();

        if ((status == MODE_CHANGE) || input_mode_change) {
            output_mode = get_output_mode(&input_mode, cur_avconfig->ad_mode_id, &vm_conf, &vmode_in, &vmode_out);

            if (output_mode != NULL) {
                printf("Output mode %d (%s) selected\n", output_mode->id, vmode_out.name);

                // configure output pixel clock
                if (vmode_out.si_pclk_mult != 0)
                    si5351_set_integer_mult(&si_dev, SI_PLLA, SI_CLK1, SI_CLKIN, output_mode->src_params->c1_hz, vmode_out.si_pclk_mult, vmode_out.si_ms_conf.outdiv);
                else
                    si5351_set_frac_mult(&si_dev, SI_PLLA, SI_CLK1, SI_CLKIN, 0, 0, 0, &vmode_out.si_ms_conf);

                // configure audio MCLK
#ifdef NEOGEO
                si5351_set_frac_mult(&si_dev, SI_PLLB, SI_CLK6, SI_CLKIN, 0, 0, 0, (si5351_ms_config_t*)&output_mode->src_params[cur_avconfig->neogeo_freq].vclk_to_mclk_conf);
#else
                si5351_set_frac_mult(&si_dev, SI_PLLB, SI_CLK6, SI_CLKIN, 0, 0, 0, (si5351_ms_config_t*)&output_mode->src_params->vclk_to_mclk_conf);
#endif

                update_osd_size(&vmode_out);
                update_sc_config(&vmode_in, &vmode_out, &vm_conf, cur_avconfig);
                adv7513_set_pixelrep_vic(&advtx_dev, vmode_out.tx_pixelrep, vmode_out.hdmitx_pixr_ifr, vmode_out.vic);
            }
        } else if (status == SC_CONFIG_CHANGE) {
            update_sc_config(&vmode_in, &vmode_out, &vm_conf, cur_avconfig);
        }

        adv7513_check_hpd_power(&advtx_dev);
        adv7513_update_config(&advtx_dev, &cur_avconfig->adv7513_cfg);

        usleep(WAITLOOP_SLEEP_US);
    }

    return 0;
}

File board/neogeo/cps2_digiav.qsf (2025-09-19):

# -------------------------------------------------------------------------- #
#
# Copyright (C) 2016  Intel Corporation. All rights reserved.
# Your use of Intel Corporation's design tools, logic functions
# and other software and tools, and its AMPP partner logic
# functions, and any output files from any of the foregoing
# (including device programming or simulation files), and any
# associated documentation or information are expressly subject
# to the terms and conditions of the Intel Program License
# Subscription Agreement, the Intel Quartus Prime License Agreement,
# the Intel MegaCore Function License Agreement, or other
# applicable license agreement, including, without limitation,
# that your use is for the sole purpose of programming logic
# devices manufactured by Intel and sold by Intel or its
# authorized distributors.  Please refer to the applicable
# agreement for further details.
#
# -------------------------------------------------------------------------- #
#
# Quartus Prime
# Version 16.1.0 Build 196 10/24/2016 SJ Lite Edition
# Date created = 23:25:51  November 29, 2016
#
# -------------------------------------------------------------------------- #
#
# Notes:
#
# 1) The default values for assignments are stored in the file:
#		cps2_digiav_assignment_defaults.qdf
#    If this file doesn't exist, see file:
#		assignment_defaults.qdf
#
# 2) Altera recommends that you do not modify this file. This
#    file is updated automatically by the Quartus Prime software
#    and any changes you make may be lost or overwritten.
#
# -------------------------------------------------------------------------- #


set_global_assignment -name FAMILY "Cyclone 10 LP"
set_global_assignment -name DEVICE 10CL025YE144C8G
set_global_assignment -name TOP_LEVEL_ENTITY cps2_digiav
set_global_assignment -name ORIGINAL_QUARTUS_VERSION 16.1.0
set_global_assignment -name PROJECT_CREATION_TIME_DATE "23:25:51  NOVEMBER 29, 2016"
set_global_assignment -name LAST_QUARTUS_VERSION "24.1std.0 Lite Edition"
set_global_assignment -name PROJECT_OUTPUT_DIRECTORY output_files
set_global_assignment -name MIN_CORE_JUNCTION_TEMP 0
set_global_assignment -name MAX_CORE_JUNCTION_TEMP 85
set_global_assignment -name DEVICE_FILTER_PACKAGE TQFP
set_global_assignment -name DEVICE_FILTER_PIN_COUNT 144
set_global_assignment -name ERROR_CHECK_FREQUENCY_DIVISOR 1
set_global_assignment -name POWER_PRESET_COOLING_SOLUTION "NO HEAT SINK WITH STILL AIR"
set_global_assignment -name POWER_BOARD_THERMAL_MODEL "NONE (CONSERVATIVE)"
set_global_assignment -name TIMING_ANALYZER_MULTICORNER_ANALYSIS ON
set_global_assignment -name SMART_RECOMPILE ON
set_global_assignment -name VERILOG_INPUT_VERSION SYSTEMVERILOG_2005
set_global_assignment -name VERILOG_SHOW_LMF_MAPPING_MESSAGES OFF
set_global_assignment -name ENABLE_OCT_DONE OFF
set_global_assignment -name ENABLE_CONFIGURATION_PINS OFF
set_global_assignment -name ENABLE_BOOT_SEL_PIN OFF
set_global_assignment -name STRATIXV_CONFIGURATION_SCHEME "PASSIVE SERIAL"
set_global_assignment -name USE_CONFIGURATION_DEVICE ON
set_global_assignment -name CYCLONEIII_CONFIGURATION_DEVICE EPCS16
set_global_assignment -name CRC_ERROR_OPEN_DRAIN OFF
set_global_assignment -name STRATIX_DEVICE_IO_STANDARD "3.3-V LVTTL"
set_global_assignment -name OUTPUT_IO_TIMING_NEAR_END_VMEAS "HALF VCCIO" -rise
set_global_assignment -name OUTPUT_IO_TIMING_NEAR_END_VMEAS "HALF VCCIO" -fall
set_global_assignment -name OUTPUT_IO_TIMING_FAR_END_VMEAS "HALF SIGNAL SWING" -rise
set_global_assignment -name OUTPUT_IO_TIMING_FAR_END_VMEAS "HALF SIGNAL SWING" -fall
set_global_assignment -name PARTITION_NETLIST_TYPE SOURCE -section_id Top
set_global_assignment -name PARTITION_FITTER_PRESERVATION_LEVEL PLACEMENT_AND_ROUTING -section_id Top
set_global_assignment -name PARTITION_COLOR 16764057 -section_id Top
set_location_assignment PIN_144 -to BTN_volminus
set_location_assignment PIN_101 -to HDMI_TX_RD[5]
set_location_assignment PIN_103 -to HDMI_TX_RD[6]
set_location_assignment PIN_106 -to HDMI_TX_RD[7]
set_location_assignment PIN_100 -to HDMI_TX_RD[4]
set_location_assignment PIN_99 -to HDMI_TX_RD[3]
set_location_assignment PIN_98 -to HDMI_TX_RD[2]
set_location_assignment PIN_87 -to HDMI_TX_RD[1]
set_location_assignment PIN_86 -to HDMI_TX_RD[0]
set_location_assignment PIN_85 -to HDMI_TX_GD[7]
set_location_assignment PIN_83 -to HDMI_TX_GD[6]
set_location_assignment PIN_77 -to HDMI_TX_GD[5]
set_location_assignment PIN_76 -to HDMI_TX_GD[4]
set_location_assignment PIN_72 -to HDMI_TX_GD[3]
set_location_assignment PIN_71 -to HDMI_TX_GD[2]
set_location_assignment PIN_69 -to HDMI_TX_GD[1]
set_location_assignment PIN_67 -to HDMI_TX_GD[0]
set_location_assignment PIN_60 -to HDMI_TX_BD[6]
set_location_assignment PIN_59 -to HDMI_TX_BD[5]
set_location_assignment PIN_68 -to HDMI_TX_PCLK
set_location_assignment PIN_58 -to HDMI_TX_BD[4]
set_location_assignment PIN_51 -to HDMI_TX_BD[3]
set_location_assignment PIN_50 -to HDMI_TX_BD[2]
set_location_assignment PIN_49 -to HDMI_TX_BD[1]
set_location_assignment PIN_44 -to HDMI_TX_BD[0]
set_location_assignment PIN_43 -to HDMI_TX_DE
set_location_assignment PIN_42 -to HDMI_TX_HS
set_location_assignment PIN_39 -to HDMI_TX_VS
set_location_assignment PIN_46 -to HDMI_TX_I2S_DATA
set_location_assignment PIN_32 -to HDMI_TX_I2S_WS
set_location_assignment PIN_33 -to HDMI_TX_I2S_BCK
set_location_assignment PIN_65 -to HDMI_TX_INT_N
set_location_assignment PIN_143 -to BTN_volplus
set_location_assignment PIN_11 -to I2S_DATA
set_location_assignment PIN_10 -to I2S_WS
set_location_assignment PIN_22 -to I2S_BCK
set_location_assignment PIN_31 -to CSYNC_in
set_location_assignment PIN_28 -to SHADOW_in
set_location_assignment PIN_25 -to VCLK_in
set_location_assignment PIN_142 -to scl
set_location_assignment PIN_141 -to sda
set_location_assignment PIN_137 -to R_in[1]
set_location_assignment PIN_135 -to R_in[2]
set_location_assignment PIN_133 -to R_in[3]
set_location_assignment PIN_132 -to R_in[4]
set_location_assignment PIN_129 -to DARK_in
set_location_assignment PIN_128 -to R_in[0]
set_location_assignment PIN_127 -to G_in[0]
set_location_assignment PIN_126 -to B_in[0]
set_location_assignment PIN_114 -to G_in[4]
set_location_assignment PIN_115 -to G_in[3]
set_location_assignment PIN_120 -to G_in[2]
set_location_assignment PIN_121 -to G_in[1]
set_location_assignment PIN_125 -to B_in[4]
set_location_assignment PIN_113 -to B_in[1]
set_location_assignment PIN_112 -to B_in[2]
set_location_assignment PIN_111 -to B_in[3]
set_location_assignment PIN_66 -to HDMI_TX_BD[7]
set_global_assignment -name CYCLONEII_RESERVE_NCEO_AFTER_CONFIGURATION "USE AS REGULAR IO"
set_global_assignment -name RESERVE_DATA0_AFTER_CONFIGURATION "USE AS REGULAR IO"
set_global_assignment -name RESERVE_DATA1_AFTER_CONFIGURATION "USE AS REGULAR IO"
set_global_assignment -name RESERVE_FLASH_NCE_AFTER_CONFIGURATION "USE AS REGULAR IO"
set_global_assignment -name RESERVE_DCLK_AFTER_CONFIGURATION "USE AS REGULAR IO"
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

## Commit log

2017-04-28 fix audio and fade
    [cps2_digiav.qsf]
2017-08-28 Prepare for first public release
    * integrate new sync processing code from ossc
    * add PCB files
    [cps2_digiav-B.Cu.gbl, cps2_digiav-B.Mask.gbs, cps2_digiav-B.Paste.gbp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]
2017-08-31 First official release (v0.50).
    [cps2_digiav_BOM.xls]
2018-02-02 This is a combination of 10 commits.
    Moved ICs to top, made to fit ontop of CPS2 DIPs
    Added ADV7513
    update lib path
    Finished power section of ADV7531
    initial layout of ADV7513
    Added Si5351C
    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
    [cps2_digiav.kicad_pcb, cps2_digiav.sch, fpga.sch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]
2018-02-02 fix schematic and library linkage issues
    [cps2_digiav.kicad_pcb, cps2_digiav.sch, fpga.sch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]
2018-02-02 prepare working space for Rev 2
    Rename PCB folder, remove files referring to Rev 1 and update README.
    [cps2_digiav-B.Cu.gbl, cps2_digiav-B.Mask.gbs, cps2_digiav-B.Paste.gbp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]
2018-02-15 finalize schematic and do initial placement on PCB
    [cps2_digiav.kicad_pcb, cps2_digiav.sch, fpga.sch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]
2018-03-28 pcb: signal routing mostly done
    [cps2_digiav.kicad_pcb, cps2_digiav.sch, fpga.sch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]
2018-04-23 finalize rev. 2.0 pcb
    [cps2_digiav-B.Cu.gbl, cps2_digiav-B.Mask.gbs, cps2_digiav-B.Paste.gbp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]
2018-06-18 add Rev2 BOM
    [bom.xls]
2018-07-06 use CPS2 voldown button for vertical adjustment
2018-08-05 fix scanlines and add bitstream files
    [cps2_digiav.qsf]
2018-11-24 update PCB to v2.1
    [bom.xls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]
2019-01-06 update documentation to match v2.1 PCB
2019-01-26 audio ASRC implementation
    [fir_2ch_audio_param.txt]
2019-02-07 fix scanlines and FIR coefficients
    [fir_2ch_audio_param.txt]
2019-06-12 fix audio code mismatch and update instructions
    [fir_2ch_audio_param.txt]
2019-09-26 fix outdated BOM
    [bom.xls]
2020-03-21 update drivers and code to enable resolution switching
2020-04-08 reorganize repo hierarchy
    * simplifies porting of the project to other platforms
    [fir_2ch_audio_param.txt]
2020-04-08 integrate cps1 branch under new hierarchy
    [bom.xls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]
2020-04-09 integrate cps3 branch under new hierarchy
    [fir_2ch_audio_param.txt]
2020-04-13 toaplan2: add preliminary support
    [fir_2ch_audio_param.txt]
2020-04-15 rtl/sw/ip_common: change source identification
    Use VCLK cycles as part of board/mode identification
2020-04-15 cps2: misc improvements
    * fix 240p audio
    * increase button debounce time
    * add 1280x1024 and 1600x1200 output modes
    [cps2_digiav.qsf]
2020-04-17 toaplan2: set better balance between OPM and ADPCM audio
    [fir_2ch_audio_param.txt]
2020-04-18 toaplan2: add PLL parameters for boards with standard sync
2020-04-18 cps1: fix 240p audio
    [cps2_digiav.qsf]
2020-10-18 update all board firmwares to v0.91
2021-04-15 add support for Neo Geo
    [fir_2ch_audio_param.txt]
2021-05-15 neogeo: fix reversed stereo and improve darkbit handling
    [cps2_digiav.qsf]
2023-10-19 update instructions
    * add note about CPS3 syncs
    * add info about alternative button arrangements
2023-10-29 neogeo: add AES instructions and ADC adapter files
    [bom.xls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]
2024-02-18 update CPS1 adapter with CPS 1.5 Multi support
    [bom.xls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]

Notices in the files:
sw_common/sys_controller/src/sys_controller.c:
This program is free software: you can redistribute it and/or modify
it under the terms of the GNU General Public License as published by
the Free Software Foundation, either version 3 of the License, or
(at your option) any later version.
